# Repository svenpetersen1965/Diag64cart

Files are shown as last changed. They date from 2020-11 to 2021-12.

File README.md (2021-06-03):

# Diag64cart
The Diag64cart is a C64/C128 cartridge PCB, that is especially made for the need of diagnostic software, like Dead Test Rev. 781220 and Diagnostic Rev. 586220. The Diag64cart is derived from the Versa64cart (https://github.com/bwack/Versa64Cart), it lacks of the ability to be a 16k cartridge, though.
The geometry of this cart was especially made for the cheap Maszczyk KM-20 and the Kradex Z7 cartridge cases. Those are available from https://restore-store.de/ or https://www.tme.eu.
Dead Test and Diagnostic reside in two different address spaces of the C64. Also, they are differently configured via GAME  or EXROM and use different chip select signals (ROMH or ROML). 

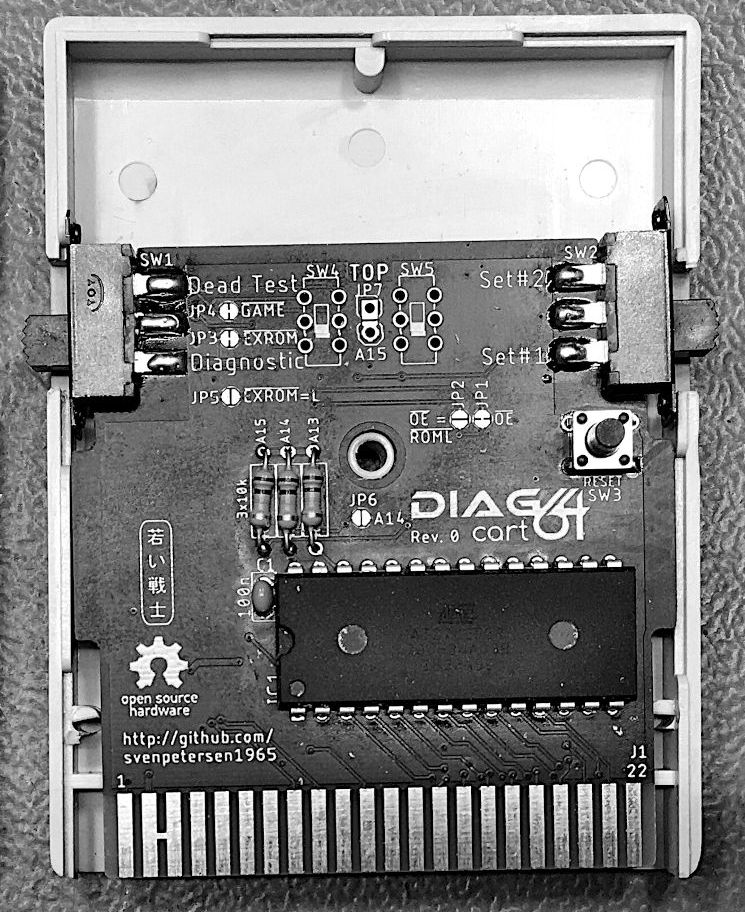
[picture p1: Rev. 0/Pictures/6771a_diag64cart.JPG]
Diag64cart


This repository contains binary files from other projects. The sources can be found in documen 164-6-01-** or here:
1.	(Commodore) Diagnostic Rev. 586220 (C64) (Version +0.5):  http://blog.worldofjani.com/?p=164
2.	(Commodore) Dead Test Rev. 781220 (C64):  http://blog.worldofjani.com/?p=164
3.	STID Dead Test (v1.2.0): https://github.com/stid/kick-c64-dead-test
4.	(Commodore) Diagnostic Rev. 785260 (C128):  http://blog.worldofjani.com/?p=164
5.	(Commodore) Diagnostic Rev. 588121 (C128):  http://blog.worldofjani.com/?p=164
6.	1541 Diagnostic (World of Jani): : http://blog.worldofjani.com/?p=2180
7.	Diag 4.1.1.: http://blog.worldofjani.com/?p=164 

BOM value (12.12.2020): 9.79€

Check out the 3D printed cartridge case from <a href="https://www.thingiverse.com/thing:4759098">retrorewind.ca</a>.

# The burn-In Software
This software requires modification of the default Configuration, since all four cartridges require EXROM=0 and Chip Select=ROML.

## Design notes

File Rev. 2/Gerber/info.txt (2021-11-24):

      
       Board: Diag64Cart
       Rev.:  2
  
       Files:
       ======
  
       All Gerber files are generated in extended gerber format (RS274X)
       *.TOP        : Film top copper
       *.BOT        :  -"- bottom copper
       *.STC        :  -"- top soldermask 
       *.STS        :  -"- bottom soldermask
       *.PLC        :  -"- silk screen top
       *.DK         : Drills plated Through (Excellon)
       *.NDK        : Drills not plated Through (Excellon)
       *.OUT        : Board outline

       Board Size:
       ===========
       Length     :   66.0 mm
       Width      :   63.3 mm
       Thickness  :   1.6 mm
       Material   :   FR 4
       Copper     :   35 um
       Surface    :   HASL
       
       Remarks:
       ========
       minimum drill: 0.35mm
       minimum width: 8 mil
       minimum distance: 6 mil

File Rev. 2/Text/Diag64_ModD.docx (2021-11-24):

Commodore C64: Diag64cart Rev. 2

Module Description

# Introduction

The Diag64cart is a C64/C128 cartridge PCB, that is especially made for the need of diagnostic software, like Dead Test Rev. 781220 and Diagnostic Rev. 586220. The Diag64cart is derived from the Versa64cart (https://github.com/bwack/Versa64Cart), it lacks of the ability to be a 16k cartridge, though.

The geometry of this cart was especially made for the cheap Maszczyk (https://www.maszczyk.pl/en.html) KM-20 and the Kradex (https://www.kradex.de/) Z7 cartridge cases. Those are available from https://restore-store.de/ or https://www.tme.eu.

Dead Test and Diagnostic reside in two different address spaces of the C64. Also, they are differently configured via or and use different chip select signals ( or ).

# Select Switches

While Dead Test replaces the Kernal, Diagnostic is an 8k auto-start cartridge at address $8000. Diag64cart has a fix assignment of EPROM offset addresses (via A13) and the cartridge type, which is done by the left DTDP switch SW1.

The right switch (SW2) only switches the EPROM offset address A14. This results in four possible software banks in the EPROM. The use of 27C256 or 27C512 is recommended.

The switches are a cheap, simple and comfortable way to reconfigure the cartridge for the different diagnostic tools. The configuration of the cartridge can be modified with solder bridges.

SW1 | SW2 | | | Chip Select | A13 | A14 | Type | EPROM
down | down | HIGH | LOW | | LOW | LOW | Diagnostic | $0000
up | down | LOW | HIGH | | HIGH | LOW | Dead Test | $2000
down | up | HIGH | LOW | | LOW | HIGH | Diagnostic | $4000
up | up | LOW | HIGH | | HIGH | HIGH | Dead Test | $6000

Table 1: Default Configuration: assignment of switches and software type

The connection between SW1, , , chip select and A13 implies an order of the type of software/cartridge in the EPROM memory.

Do not confuse the EPROM offset address with the memory address of the cartridge in the C64/C128. A selected cartridge will appear in the computer’s address, that is specified by the chip select (that is $8000 for and $C000 for ). The EPROM offset address is the address in the programming buffer/EPROM, where the binaries reside.

# Configuration with solder bridges

The default configuration is described in the previous chapter. This can be modified with solder bridges.

E.G. the C128 works differently than the C64. If the C128 finds either or LOW, it will boot into the C64 mode. For a C128 cartridge, both signals have to be high.

Solder bridge | Default | When closed | Note
JP1 | closed | Chip select () switched by SW1 | If JP2 is closed, open JP1
JP2 | open | Chip select always | e.g. for only diagnostic software or C128 mode only
JP3 | closed | switched by SW1, A13 = | Open for permanent settings for
JP4 | closed | switched by SW1 | Open for permanent settings for
JP5 | open | always LOW | e.g. for C64 diagnostic only
JP6 | open | A14 always LOW | In case only two software required and A14 not installed
JP7 | open | A15 always LOW | Close for EPROM type 27C512
JP8 | open | always LOW | e.g. for C64 dead test only

Table 2: Configuration of the solder bridges

# Example configurations

## EPROM Type 27C512

If a 27C512 is used, it might be desired to program the EPROM starting at offset address $0000. For this purpose, A15 has to be LOW. This requires JP7 to be closed.

## EPROM Type 27C256

This is the default EPROM type. No modifications are required. JP7 is open be default, that means A15 is HIGH (that is the VPP input on a 27C256).

## EPROM Type 27C128

This 16k EPROM can hold two 8k software. In this case, SW2 (which switches A14 between LOW and HIGH =open, due to the pull-up resistor). In a 27C128, this pin is /PGM, which should be HIGH. The switch SW2 can just be omitted, no further modification required, since the pull-up resistor R3 does the job.

## EPROM Type 27C64

This is actually an abuse, since a 27C64 can only hold 8k of software. So, no switch is required at all. A13 (Pin 26) is a “not connected” pin of the EPROM. The pull-up R4 can stay. It does not harm the function of the EPROM, but it is not required. In case the cartridge software resides in $8000, close JP2 and JP5. An 8k cartridge at $C000 can be achieved by bridging the solder pads of SW1 to mimic it in up position. The solder pads of the alternative switch SW4 might come in handy in this case.

## C64 and C128 Diagnostic Cartridge

The C128 requires both, and to be HIGH (=open) and the chip select () to be . For this purpose, open JP4 and JP1 and close JP2. While the 8k memory at $0000 and $4000 are reserved for C64 software and the 8k memory banks at $2000 and $6000 are reserved for C128 cartridge software.

## C128 Cartridge Only

Again, both , and , have to be HIGH (=open) and the chip select () has to be . For this purpose, open JP1, JP3, JP4 and close JP2.

## C64 Diagnostic Cartridge Only

In case it is desired to have all software reside at $8000, needs to be open, needs to be low and the chip select has to be . For this purpose, open JP1, JP3 and JP4 and close JP2 and JP5.

# Switches

The switches SW1 and SW2 are built in sideways. They are DPDT slide switches with a pin pitch of 4mm. The hole distance is 19mm (which is not important for this project, but just a part of the switches specification). The height of the switch body is 6.9mm. This is met be the reichelt.de part number T217 or the AliExpress SS22F25-G7, but obviously, there are more 199mm pitch panel mount switches, that meet these specifications.

Alternatively, there are footprints (SW4 and SW5) for the also wide spread AliExpress mini slide switches MSS22D18.

# EPROMs

Four different types/sizes of EPROMs can be used with the Versa64Cart, not all settings make sense with them. Their pin out is shown in Table 3.

The effect of the settings and the recommended configurations are shown in Table 4.

27C64
| 27C128
| | 27C256
| | | 27C512
| | | | SOCKET
Vpp | Vpp | Vpp | A15 | 1 | A15 | VCC | 28 | VCC | VCC | VCC | VCC
A12 | A12 | A12 | A12 | 2 | A12 | A14 | 27 | A14 | A14 | /PGM | /PGM
A7 | A7 | A7 | A7 | 3 | A7 | A13 | 26 | A13 | A13 | A13 | n.c.
A6 | A6 | A6 | A6 | 4 | A6 | A8 | 25 | A8 | A8 | A8 | A8
A5 | A5 | A5 | A5 | 5 | A5 | A9 | 24 | A9 | A9 | A9 | A9
A4 | A4 | A4 | A4 | 6 | A4 | A11 | 23 | A11 | A11 | A11 | A11
A3 | A3 | A3 | A3 | 7 | A3 | /OE | 22 | /G/Vpp | /G | /G | /G
A2 | A2 | A2 | A2 | 8 | A2 | A10 | 21 | A10 | A10 | A10 | A10
A1 | A1 | A1 | A1 | 9 | A1 | GND | 20 | /E | /E | /E | /E
A0 | A0 | A0 | A0 | 10 | A0 | D7 | 19 | D7 | D7 | D7 | D7
D0 | D0 | D0 | D0 | 11 | D0 | D6 | 18 | D6 | D6 | D6 | D6
D1 | D1 | D1 | D1 | 12 | D1 | D5 | 17 | D5 | D5 | D5 | D5
D2 | D2 | D2 | D2 | 13 | D2 | D4 | 16 | D4 | D4 | D4 | D4
GND | GND | GND | GND | 14 | GND | D3 | 15 | D3 | D3 | D3 | D3

Table 3: EPROM pin compatibility

EPROM | Size | A15 | A14 | A13 | 16k
27C512 | 64kx8 | yes | yes | yes | yes
27C256 | 32kx8 | HIGH | yes | yes | yes
27C128 | 16kx8 | HIGH | HIGH | yes | yes
27C64 | 8kx8 | HIGH | HIGH | HIGH | no

Table 4: Settings per EPROM type

In case Vpp is located at a dedicated pin (pin 1), A15 has no effect anymore. A HIGH level is recommended (switch is off) . The /PGM Pin should be set HIGH. The n.c. (not connected) pin should be HIGH (with pull-up) or open. For an 8k EPROM, the 16k setting makes no sense.

# Using parallel EEPROMs

There are parallel EPROMs, which fit into the EPROM sockets. They do not require erasing with a UV eraser, like EPROMs, but the price is higher.

Since they can be written, which is controlled by the signal, but the Super Expander II cartridge is lacking of this functionality, this signal has to be HIGH (inactive). The 28C256 has the A14 signal connected to Pin 1, which is A15 of the EEPROM socket. This is no problem, but it has to be kept in mind, that the jumper for A15 has effect on the bank select A14 of the EPROM.

28C64
| 28C256
| | SOCKET
n.c. | A14 | 1 | A15 | VCC | 28 | VCC | VCC
A12 | A12 | 2 | A12 | A14 | 27 | /WE | /WE
A7 | A7 | 3 | A7 | A13 | 26 | A13 | n.c
A6 | A6 | 4 | A6 | A8 | 25 | A8 | A8
A5 | A5 | 5 | A5 | A9 | 24 | A9 | A9
A4 | A4 | 6 | A4 | A11 | 23 | A11 | A11
A3 | A3 | 7 | A3 | /OE | 22 | /G/Vpp | /OE
A2 | A2 | 8 | A2 | A10 | 21 | A10 | A10
A1 | A1 | 9 | A1 | GND | 20 | /E | /CE
A0 | A0 | 10 | A0 | D7 | 19 | D7 | D7
D0 | D0 | 11 | D0 | D6 | 18 | D6 | D6
D1 | D1 | 12 | D1 | D5 | 17 | D5 | D5
D2 | D2 | 13 | D2 | D4 | 16 | D4 | D4
GND | GND | 14 | GND | D3 | 15 | D3 | D3

Table 5: EEPROM pin compatibility

EEPROM | Size | A15 | A14 | A13
28C256 | 32kx8 | =A14 | OPEN | yes
28C64 | 8kx8 | OPEN | OPEN | OPEN

Table 6: Settings per EEPROM type

# Dimensions

The dimensions are made to fit the said cartridge cases.

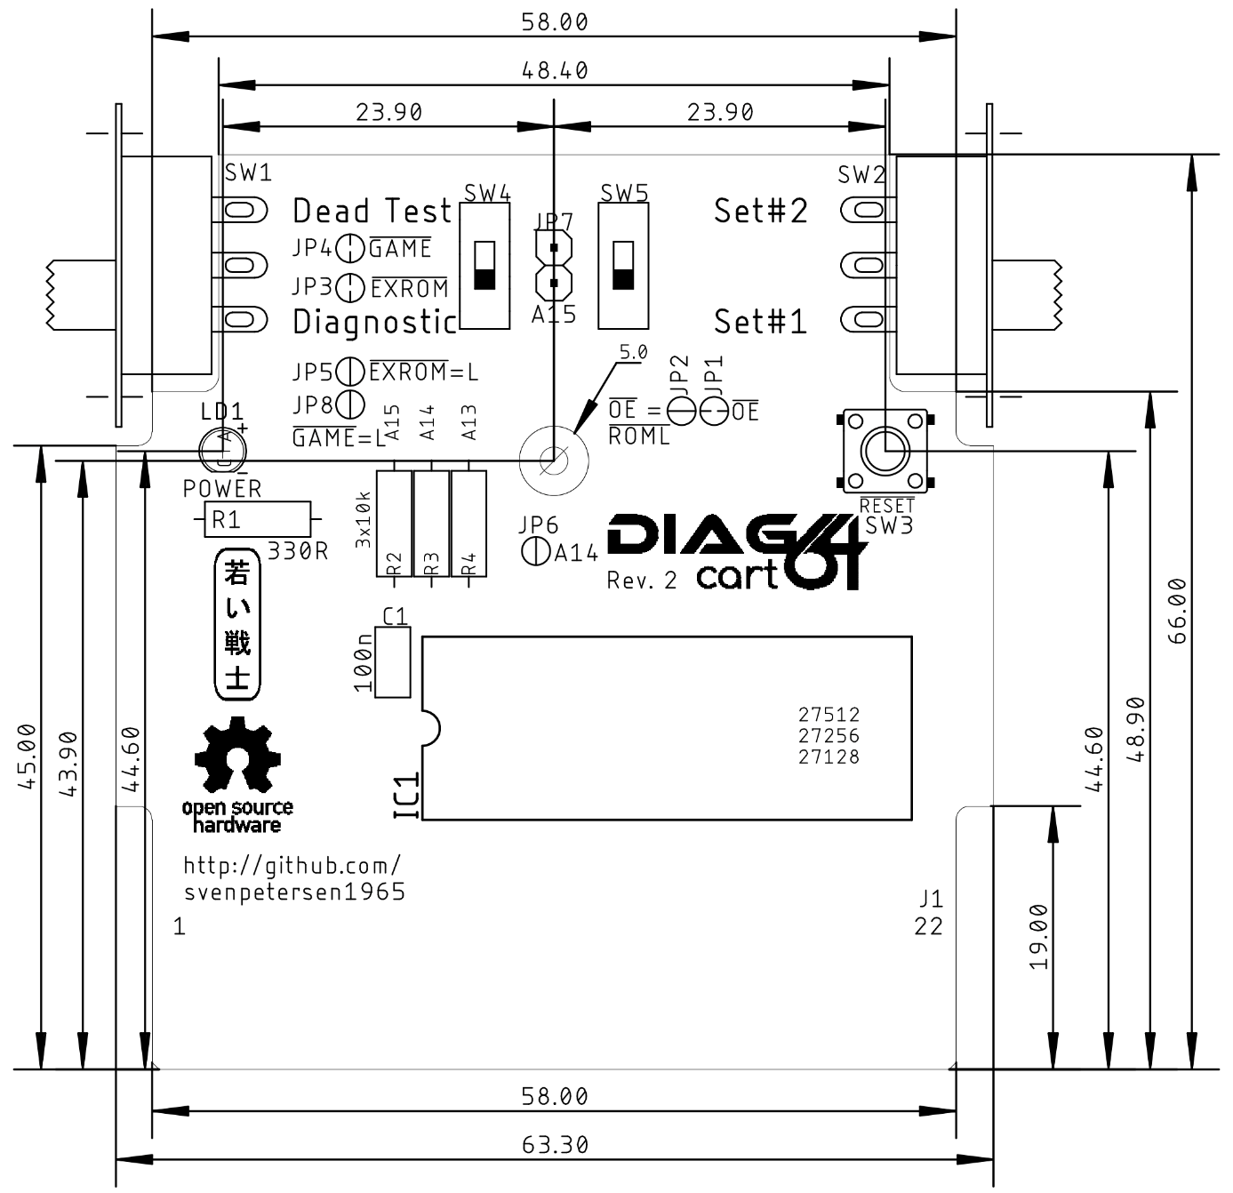
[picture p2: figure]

Figure 1: Dimensions

The Maszczyk KM-20 and the Kradex Z7 cartridge cases both fit the Diag64cart. The dimensions are slightly different, though.

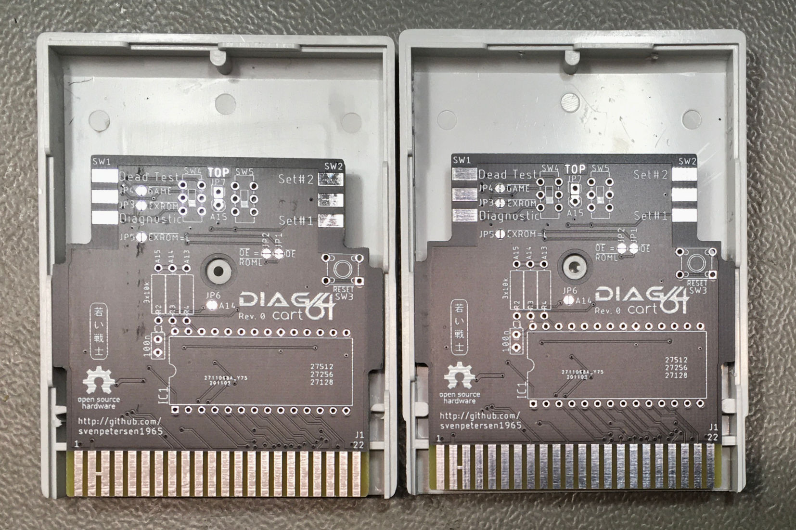
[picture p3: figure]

Figure 2: Maszczyk KM-20(left), Kradex Z7 (right)

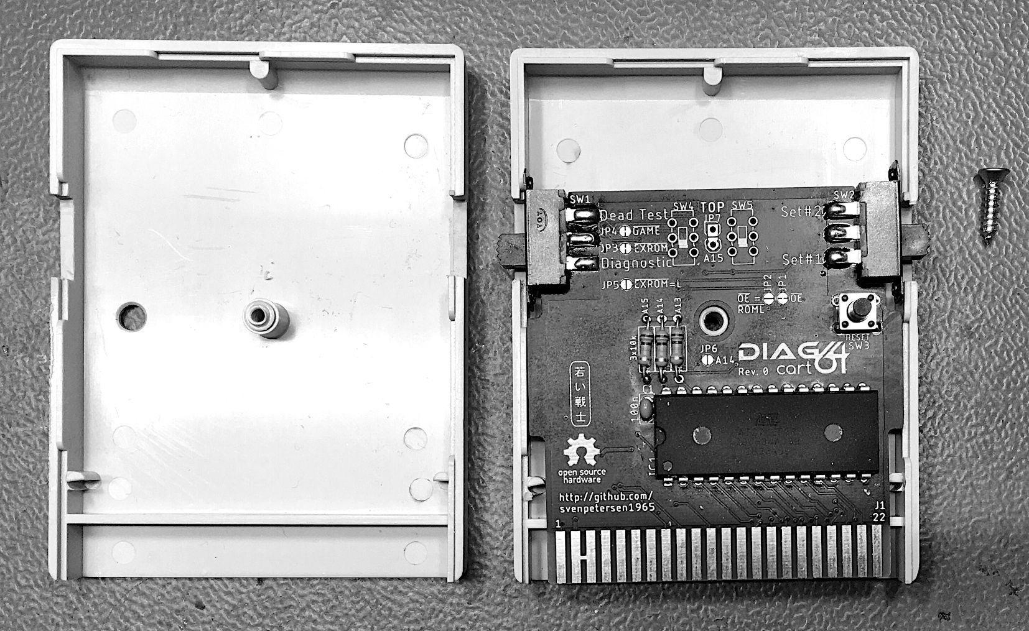
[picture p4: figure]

Figure 3: Diag64cart in the finished KM-20 case

# Suggested Software

This cartridge is made for C64 (and C128) Diagnostic software. So, the selection of suggested software is for this kind of purpose.

1. (Commodore) Diagnostic Rev. 586220 (C64) (Version +0.5)
2. (Commodore) Dead Test Rev. 781220 (C64)
3. STID Dead Test (v1.2.0)
4. (Commodore) Diagnostic Rev. 785260 (C128)
5. (Commodore) Diagnostic Rev. 588121 (C128)
6. 1541 Diagnostic (World of Jani)
7. Diag 4.1.1.

Diagnostic Rev. 586220 and Diag. 4.1.1 work with the same diagnostic harness (https://github.com/svenpetersen1965/C64-Diagnostic-Rev.-586220-Harness). While Diagnostic Rev. 586220 is still the diagnostic tool of my choice, Diag 4.1.1 is a bit different and might be useful as a second instance.

Dead Test Rev. 781220 is THE dead test program, that can reveal RAM problems without requiring a working display. The first-choice software to debug a black screen.

STID Dead Test is a modification of the Commodore Dead Test Rev. 781220 it has some nice new features (e.g. tests the SID filters). It can be obtained here: https://github.com/stid/kick-c64-dead-test. The binary files can be found in the releases of this project. No compiling and building required.

The 1541 Diagnostics is a very nice toolkit for testing and debugging a Commodore 1541 (or Oceanic OC-118) disk drive. It can be obtained here: http://blog.worldofjani.com/?p=2180

I have downloaded all other binaries from World of Jani: http://blog.worldofjani.com/?p=164

# Revision History

## Rev. 0

- Fully functional prototype

## Rev. 1

- JP8 new
- Lower corner of the “shoulders” was moved down by 6mm (19mm instead of 25mm) to reduce the movement of the PCB.

## Rev. 2

- Power LED added

Diag64_ModD.docx 24.11.2021 22:10 Drafted by Sven Petersen Page 2 of 2 Doc.-No.: 164-6-01-02

Diag64_ModD.docx 24.11.2021 22:10 Drafted by Sven Petersen Page 1 of 1 Doc.-No.: 000-6-00-00

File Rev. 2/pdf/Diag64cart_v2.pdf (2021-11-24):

# Project Documentation

## Commodore C64: Diag64cart

## Project number: 164

## Revision: 2

## Date: 24.11.2021

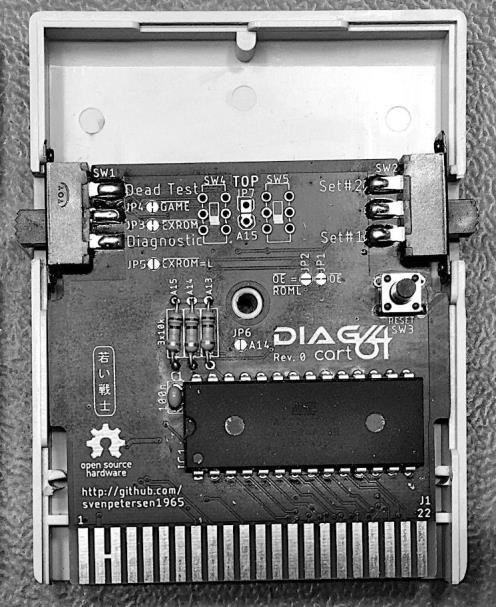
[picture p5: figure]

Diag64_ModD.docx | | 24.11.2021 22:10
Drafted by Sven Petersen | Page 1 of 8 | Doc.-No.: 164-6-01-02

### Commodore C64: Diag64cart Rev. 2

### Module Description

Table of Contents

## Introduction

The Diag64cart is a C64/C128 cartridge PCB, that is especially made for the need of diagnostic software, like Dead Test Rev. 781220 and Diagnostic Rev. 586220. The Diag64cart is derived from the Versa64cart (https://github.com/bwack/Versa64Cart), it lacks of the ability to be a 16k cartridge, though.

The geometry of this cart was especially made for the cheap Maszczyk (https://www.maszczyk.pl/en.html) KM-20 and the Kradex (https://www.kradex.de/) Z7 cartridge cases. Those are available from https://restore-store.de/ or https://www.tme.eu.

Dead Test and Diagnostic reside in two different address spaces of the C64. Also, they are differently configured via GAME or EXROM and use different chip select signals ( ROMH or ROML ).

Drafted by Sven Petersen | Page 2 of 8 | Doc.-No.: 164-6-01-02

## Select Switches

While Dead Test replaces the Kernal, Diagnostic is an 8k auto-start cartridge at address $8000. Diag64cart has a fix assignment of EPROM offset addresses (via A13) and the cartridge type, which is done by the left DTDP switch SW1.

The right switch (SW2) only switches the EPROM offset address A14. This results in four possible software banks in the EPROM. The use of 27C256 or 27C512 is recommended.

The switches are a cheap, simple and comfortable way to reconfigure the cartridge for the different diagnostic tools. The configuration of the cartridge can be modified with solder bridges.

SW1 | SW2 | GAME | EXROM
Chip Select | A13 | A14 | Type | EPROM
down | down | HIGH | LOW | ROML | LOW | LOW | Diagnostic | $0000
up | down | LOW | HIGH | ROMH | HIGH | LOW | Dead Test | $2000
down | up | HIGH | LOW | ROML | LOW | HIGH | Diagnostic | $4000
up | up | LOW | HIGH | ROMH | HIGH | HIGH | Dead Test | $6000

Table 1: Default Configuration: assignment of switches and software type

The connection between SW1, GAME , EXROM , chip select and A13 implies an order of the type of software/cartridge in the EPROM memory.

Do not confuse the EPROM offset address with the memory address of the cartridge in the C64/C128. A selected cartridge will appear in the computer’s address, that is specified by the chip

select (that is $8000 for ROML and $C000 for ROMH ). The EPROM offset address is the address in the programming buffer/EPROM, where the binaries reside.

## Configuration with solder bridges

The default configuration is described in the previous chapter. This can be modified with solder bridges.

E.G. the C128 works differently than the C64. If the C128 finds either GAME or EXROM LOW, it will boot into the C64 mode. For a C128 cartridge, both signals have to be high.

Solder bridge Default When closed | Note
JP1 | closed | Chip select ( OE ) switched by SW1 | If JP2 is closed, open JP1
JP2 | open | Chip select always ROML | e.g. for only diagnostic software or C128 mode only
JP3 | closed | EXROM switched by SW1, A13 = EXROM | Open for permanent settings for EXROM
JP4 | closed | GAME switched by SW1 | Open for permanent settings for GAME
JP5 | open | EXROM always LOW | e.g. for C64 diagnostic only
JP6 | open | A14 always LOW | In case only two software required and A14 not installed

Drafted by Sven Petersen | Page 3 of 8 | Doc.-No.: 164-6-01-02
Solder bridge Default When closed | Note
JP7 | open | A15 always LOW | Close for EPROM type 27C512
JP8 | open | GAME always LOW | e.g. for C64 dead test only

Table 2: Configuration of the solder bridges

## Example configurations

### EPROM Type 27C512

If a 27C512 is used, it might be desired to program the EPROM starting at offset address $0000. For this purpose, A15 has to be LOW. This requires JP7 to be closed.

### EPROM Type 27C256

This is the default EPROM type. No modifications are required. JP7 is open be default, that means A15 is HIGH (that is the VPP input on a 27C256).

### EPROM Type 27C128

This 16k EPROM can hold two 8k software. In this case, SW2 (which switches A14 between LOW and HIGH =open, due to the pull-up resistor). In a 27C128, this pin is /PGM, which should be HIGH. The switch SW2 can just be omitted, no further modification required, since the pull-up resistor R3 does the job.

### EPROM Type 27C64

This is actually an abuse, since a 27C64 can only hold 8k of software. So, no switch is required at all. A13 (Pin 26) is a “not connected” pin of the EPROM. The pull-up R4 can stay. It does not harm the function of the EPROM, but it is not required. In case the cartridge software resides in $8000, close JP2 and JP5. An 8k cartridge at $C000 can be achieved by bridging the solder pads of SW1 to mimic it in up position. The solder pads of the alternative switch SW4 might come in handy in this case.

### C64 and C128 Diagnostic Cartridge

The C128 requires both, GAME and EXROM to be HIGH (=open) and the chip select ( OE ) to

be ROML . For this purpose, open JP4 and JP1 and close JP2. While the 8k memory at $0000 and $4000 are reserved for C64 software and the 8k memory banks at $2000 and $6000 are reserved for C128 cartridge software.

### C128 Cartridge Only

Again, both , GAME and EXROM , have to be HIGH (=open) and the chip select ( OE ) has to

be ROML . For this purpose, open JP1, JP3, JP4 and close JP2.

### C64 Diagnostic Cartridge Only

In case it is desired to have all software reside at $8000, GAME needs to be open, EXROM needs

to be low and the chip select has to be ROML . For this purpose, open JP1, JP3 and JP4 and close JP2 and JP5.

Drafted by Sven Petersen | Page 4 of 8 | Doc.-No.: 164-6-01-02

## Switches

The switches SW1 and SW2 are built in sideways. They are DPDT slide switches with a pin pitch of 4mm. The hole distance is 19mm (which is not important for this project, but just a part of the switches specification). The height of the switch body is 6.9mm. This is met be the reichelt.de part number T217 or the AliExpress SS22F25-G7, but obviously, there are more 199mm pitch panel mount switches, that meet these specifications.

Alternatively, there are footprints (SW4 and SW5) for the also wide spread AliExpress mini slide switches MSS22D18.

## EPROMs

Four different types/sizes of EPROMs can be used with the Versa64Cart, not all settings make sense with them. Their pin out is shown in Table 3.

The effect of the settings and the recommended configurations are shown in Table 4.

27C64

| 27C128
| 27C256
| 27C512
| SOCKET
Vpp | Vpp | Vpp | A15 | 1 | A15 | VCC | 28 | VCC | VCC | VCC | VCC
A12 | A12 | A12 | A12 | 2 | A12 | A14 | 27 | A14 | A14 | /PGM | /PGM
A7 | A7 | A7 | A7 | 3 | A7 | A13 | 26 | A13 | A13 | A13 | n.c.
A6 | A6 | A6 | A6 | 4 | A6 | A8 | 25 | A8 | A8 | A8 | A8
A5 | A5 | A5 | A5 | 5 | A5 | A9 | 24 | A9 | A9 | A9 | A9
A4 | A4 | A4 | A4 | 6 | A4 | A11 | 23 | A11 | A11 | A11 | A11
A3 | A3 | A3 | A3 | 7 | A3 | /OE | 22 | /G/Vpp | /G | /G | /G
A2 | A2 | A2 | A2 | 8 | A2 | A10 | 21 | A10 | A10 | A10 | A10
A1 | A1 | A1 | A1 | 9 | A1 | GND | 20 | /E | /E | /E | /E
A0 | A0 | A0 | A0 | 10 | A0 | D7 | 19 | D7 | D7 | D7 | D7
D0 | D0 | D0 | D0 | 11 | D0 | D6 | 18 | D6 | D6 | D6 | D6
D1 | D1 | D1 | D1 | 12 | D1 | D5 | 17 | D5 | D5 | D5 | D5
D2 | D2 | D2 | D2 | 13 | D2 | D4 | 16 | D4 | D4 | D4 | D4
GND | GND | GND | GND | 14 | GND | D3 | 15 | D3 | D3 | D3 | D3

Table 3: EPROM pin compatibility

Drafted by Sven Petersen | Page 5 of 8 | Doc.-No.: 164-6-01-02
EPROM | Size | A15 | A14 | A13 | 16k
27C512 | 64kx8 | yes | yes | yes | yes
27C256 | 32kx8 | HIGH | yes | yes | yes
27C128 | 16kx8 | HIGH | HIGH | yes | yes
27C64 | 8kx8 | HIGH | HIGH | HIGH | no
Table 4: Settings per EPROM type

In case Vpp is located at a dedicated pin (pin 1), A15 has no effect anymore. A HIGH level is recommended (switch is off) . The /PGM Pin should be set HIGH. The n.c. (not connected) pin should be HIGH (with pull-up) or open. For an 8k EPROM, the 16k setting makes no sense.

## Using parallel EEPROMs

There are parallel EPROMs, which fit into the EPROM sockets. They do not require erasing with a UV eraser, like EPROMs, but the price is higher.

Since they can be written, which is controlled by the WE signal, but the Super Expander II cartridge is lacking of this functionality, this signal has to be HIGH (inactive). The 28C256 has the A14 signal connected to Pin 1, which is A15 of the EEPROM socket. This is no problem, but it has to be kept in mind, that the jumper for A15 has effect on the bank select A14 of the EPROM.

28C64

| 28C256
| SOCKET
n.c. | A14 | 1 | A15 | VCC | 28 | VCC | VCC
A12 | A12 | 2 | A12 | A14 | 27 | /WE | /WE
A7 | A7 | 3 | A7 | A13 | 26 | A13 | n.c
A6 | A6 | 4 | A6 | A8 | 25 | A8 | A8
A5 | A5 | 5 | A5 | A9 | 24 | A9 | A9
A4 | A4 | 6 | A4 | A11 | 23 | A11 | A11
A3 | A3 | 7 | A3 | /OE | 22 | /G/Vpp | /OE
A2 | A2 | 8 | A2 | A10 | 21 | A10 | A10
A1 | A1 | 9 | A1 | GND | 20 | /E | /CE
A0 | A0 | 10 | A0 | D7 | 19 | D7 | D7
D0 | D0 | 11 | D0 | D6 | 18 | D6 | D6
D1 | D1 | 12 | D1 | D5 | 17 | D5 | D5
D2 | D2 | 13 | D2 | D4 | 16 | D4 | D4
GND | GND | 14 | GND | D3 | 15 | D3 | D3

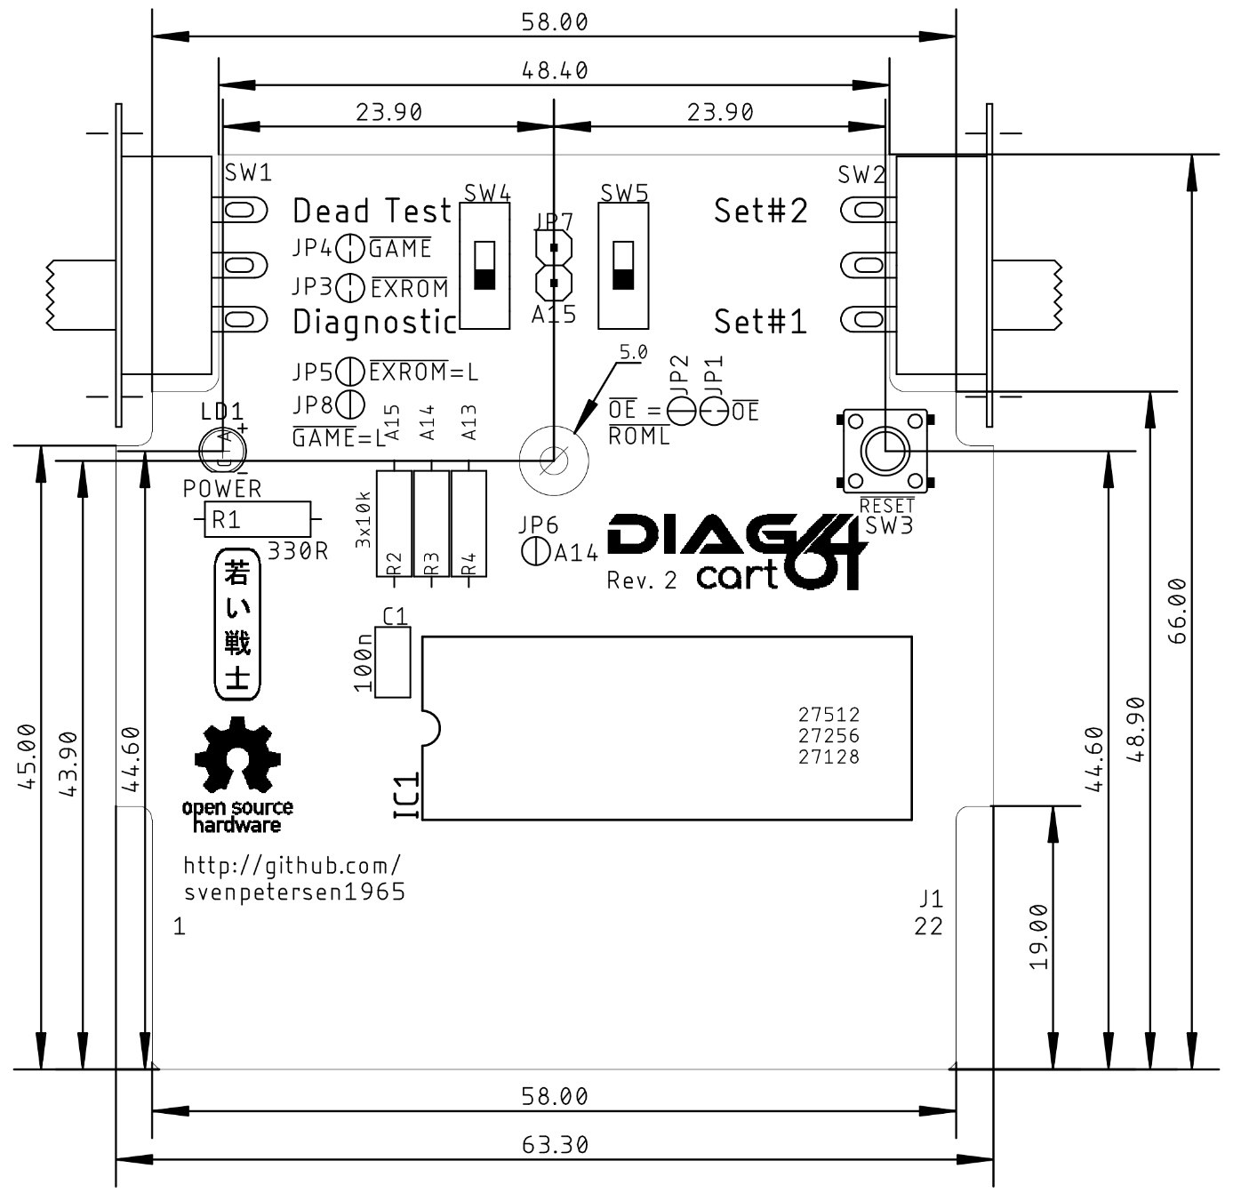
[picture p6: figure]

Drafted by Sven Petersen | Page 6 of 8 | Doc.-No.: 164-6-01-02

Table 5: EEPROM pin compatibility

EEPROM | Size | A15 | A14 | A13
28C256 | 32kx8 | =A14 | OPEN | yes
28C64 | 8kx8 | OPEN | OPEN | OPEN
Table 6: Settings per EEPROM type

## Dimensions

The dimensions are made to fit the said cartridge cases.

Figure 1: Dimensions

The Maszczyk KM-20 and the Kradex Z7 cartridge cases both fit the Diag64cart. The dimensions are slightly different, though.

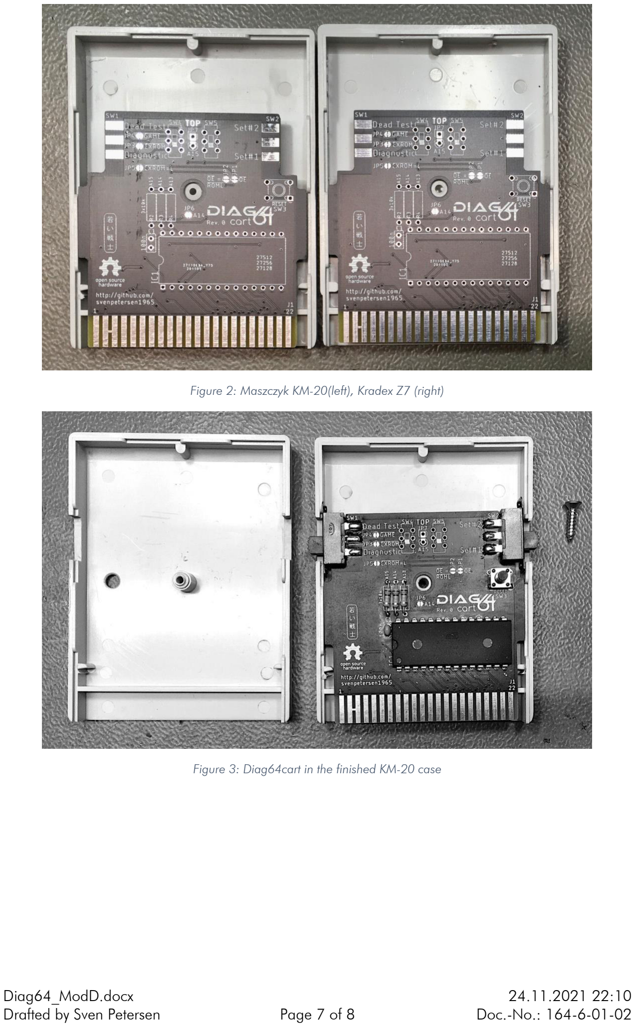
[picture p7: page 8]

Drafted by Sven Petersen | Page 7 of 8 | Doc.-No.: 164-6-01-02

Figure 2: Maszczyk KM-20(left), Kradex Z7 (right)

Figure 3: Diag64cart in the finished KM-20 case

Drafted by Sven Petersen | Page 8 of 8 | Doc.-No.: 164-6-01-02

## Suggested Software

This cartridge is made for C64 (and C128) Diagnostic software. So, the selection of suggested software is for this kind of purpose.

1. (Commodore) Diagnostic Rev. 586220 (C64) (Version +0.5)
2. (Commodore) Dead Test Rev. 781220 (C64)

### 3. STID Dead Test (v1.2.0)

4. (Commodore) Diagnostic Rev. 785260 (C128)
5. (Commodore) Diagnostic Rev. 588121 (C128)
6. 1541 Diagnostic (World of Jani)
7. Diag 4.1.1.

Diagnostic Rev. 586220 and Diag. 4.1.1 work with the same diagnostic harness (https://github.com/svenpetersen1965/C64-Diagnostic-Rev.-586220-Harness). While Diagnostic Rev. 586220 is still the diagnostic tool of my choice, Diag 4.1.1 is a bit different and might be useful as a second instance.

Dead Test Rev. 781220 is THE dead test program, that can reveal RAM problems without requiring a working display. The first-choice software to debug a black screen.

STID Dead Test is a modification of the Commodore Dead Test Rev. 781220 it has some nice new features (e.g. tests the SID filters). It can be obtained here: https://github.com/stid/kick-c64-dead-test. (https://github.com/stid/kick-c64-dead-test) The binary files can be found in the releases of this project. No compiling and building required.

The 1541 Diagnostics is a very nice toolkit for testing and debugging a Commodore 1541 (or Oceanic OC-118) disk drive. It can be obtained here: http://blog.worldofjani.com/?p=2180

I have downloaded all other binaries from World of Jani: http://blog.worldofjani.com/?p=164

## Revision History

### Rev. 0

- Fully functional prototype

### Rev. 1

- JP8 new

### - Lower corner of the “shoulders” was moved down by 6mm (19mm instead of 25mm) to

reduce the movement of the PCB.

### Rev. 2

- Power LED added

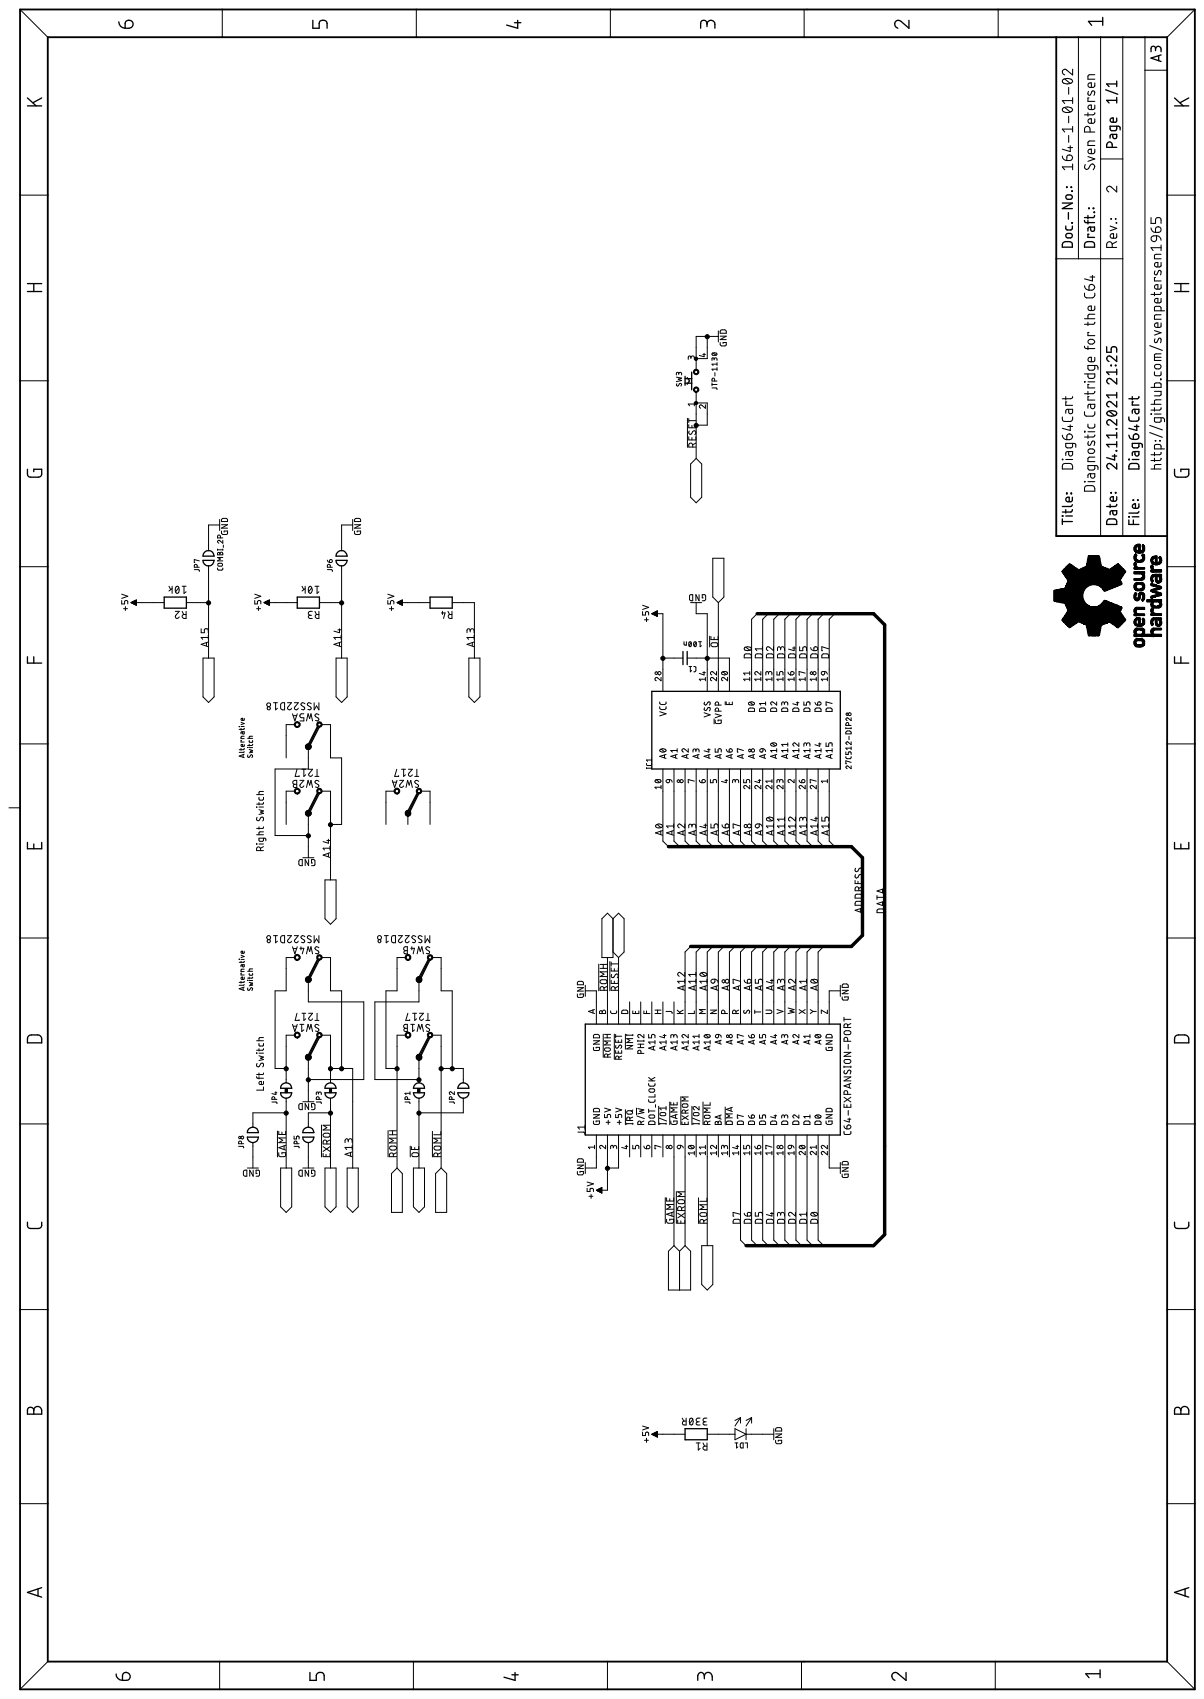
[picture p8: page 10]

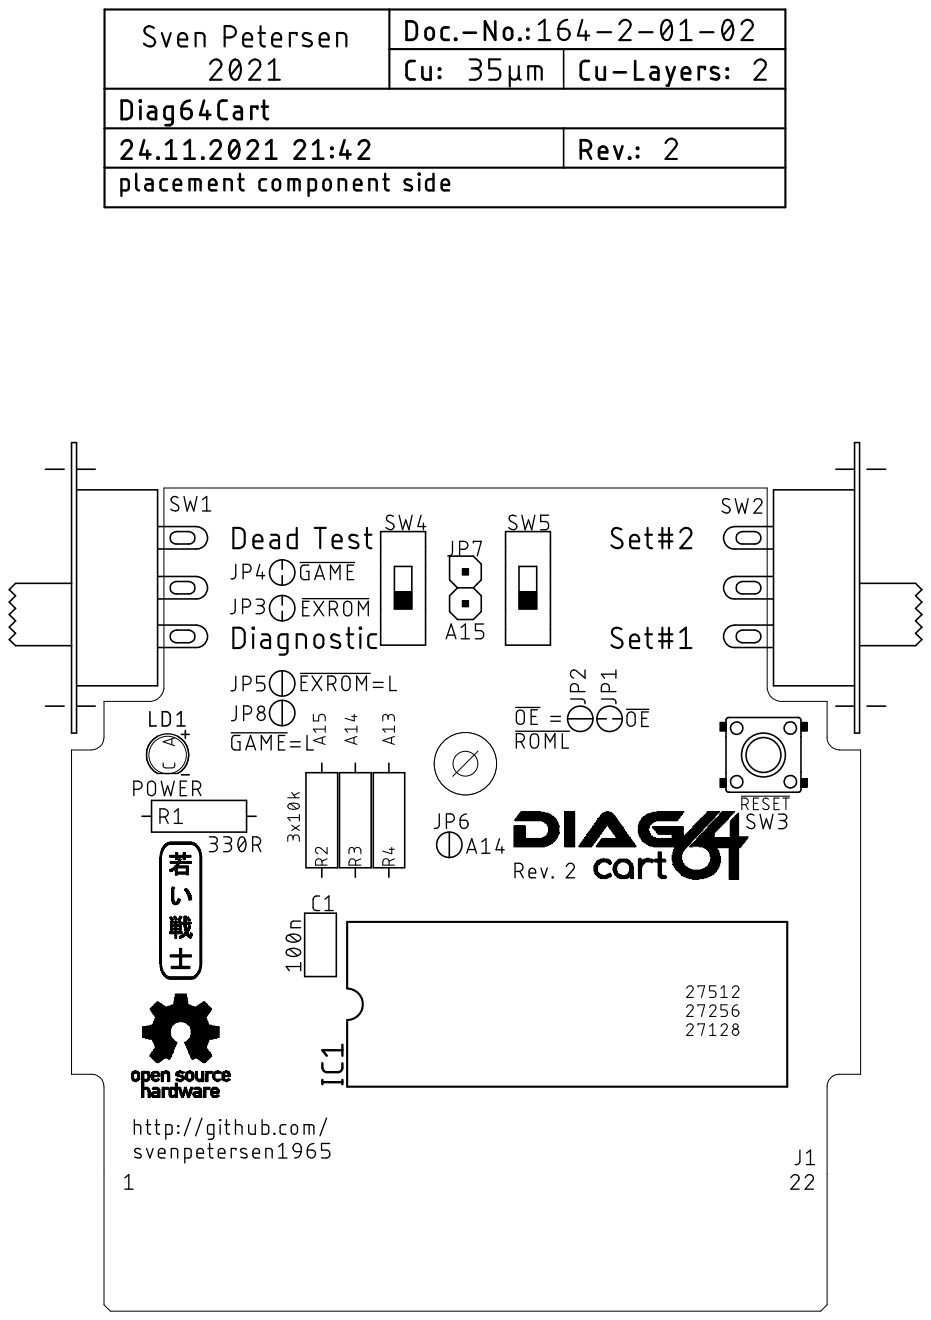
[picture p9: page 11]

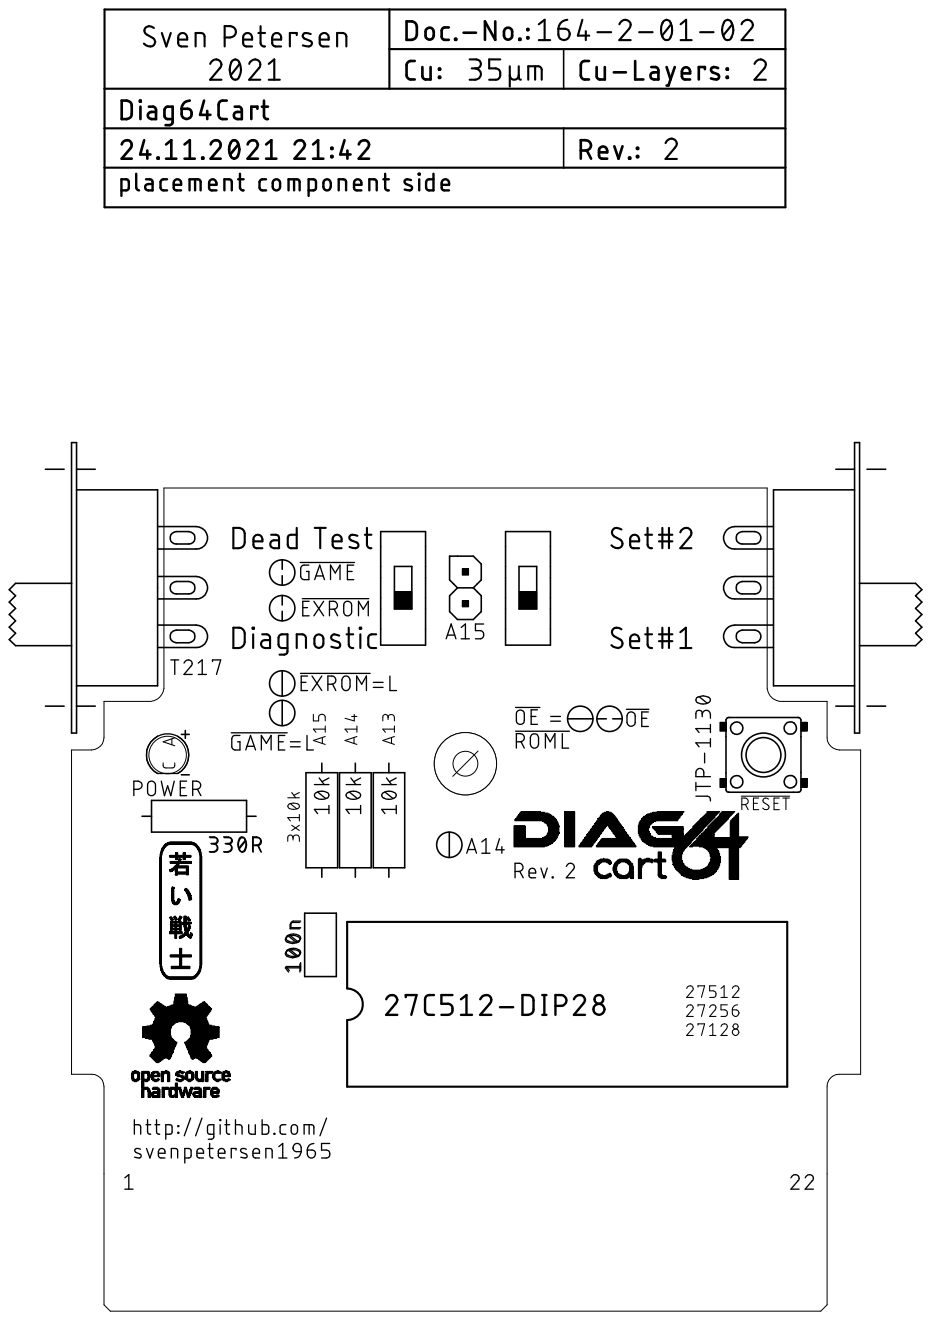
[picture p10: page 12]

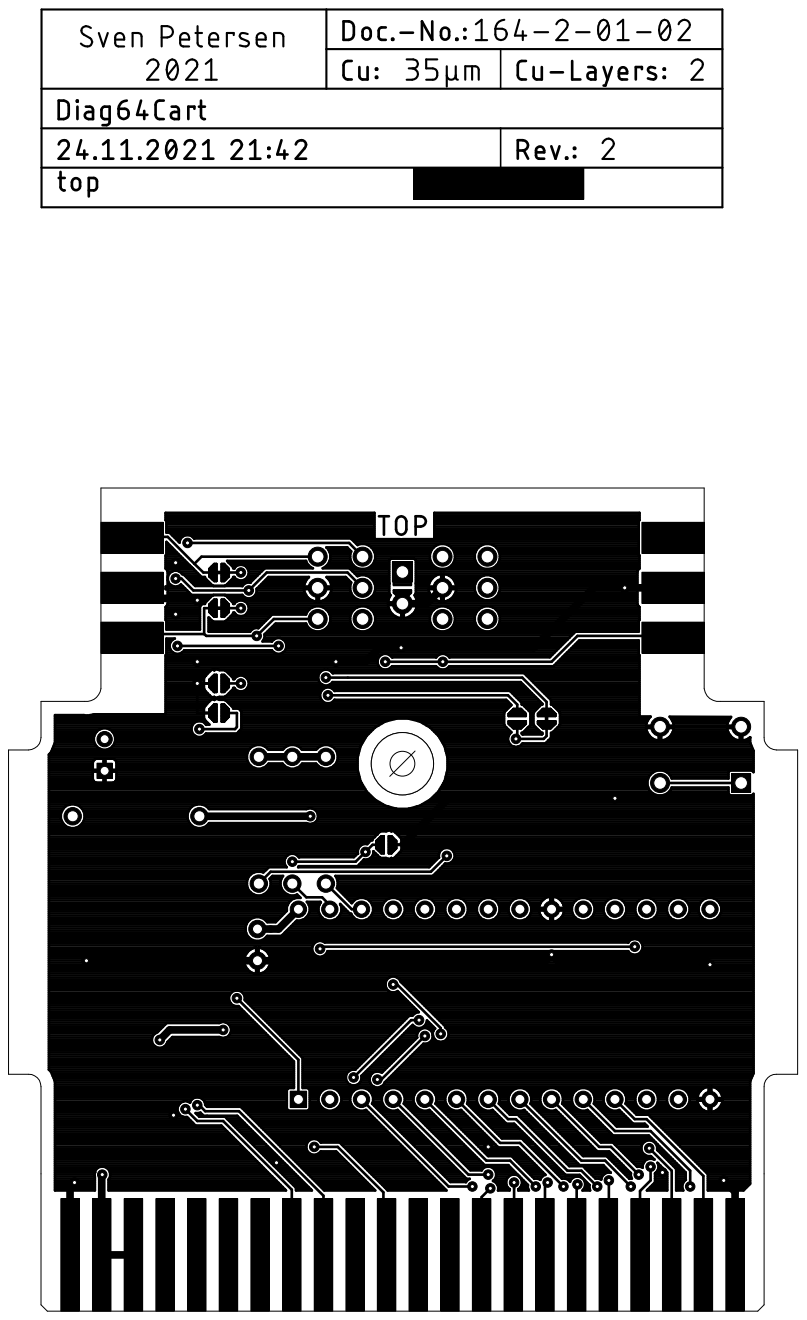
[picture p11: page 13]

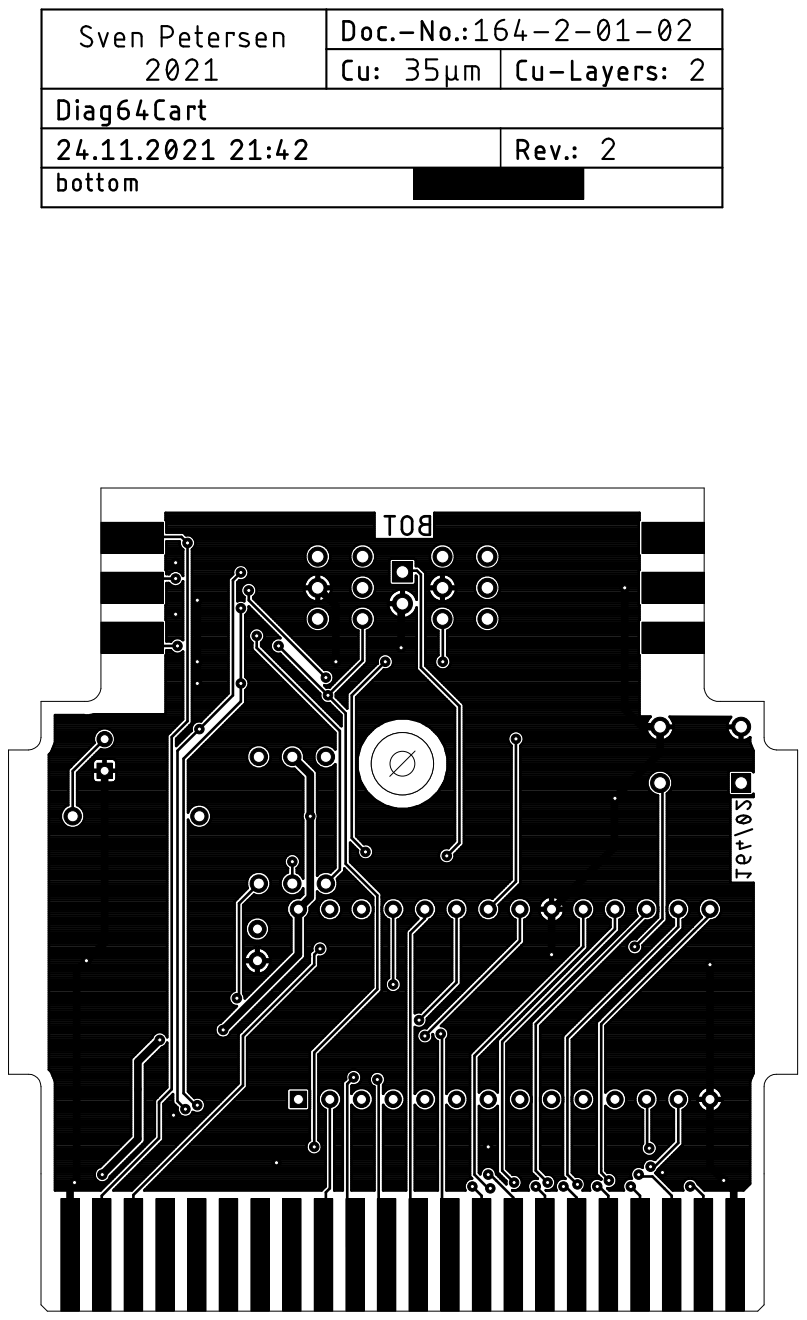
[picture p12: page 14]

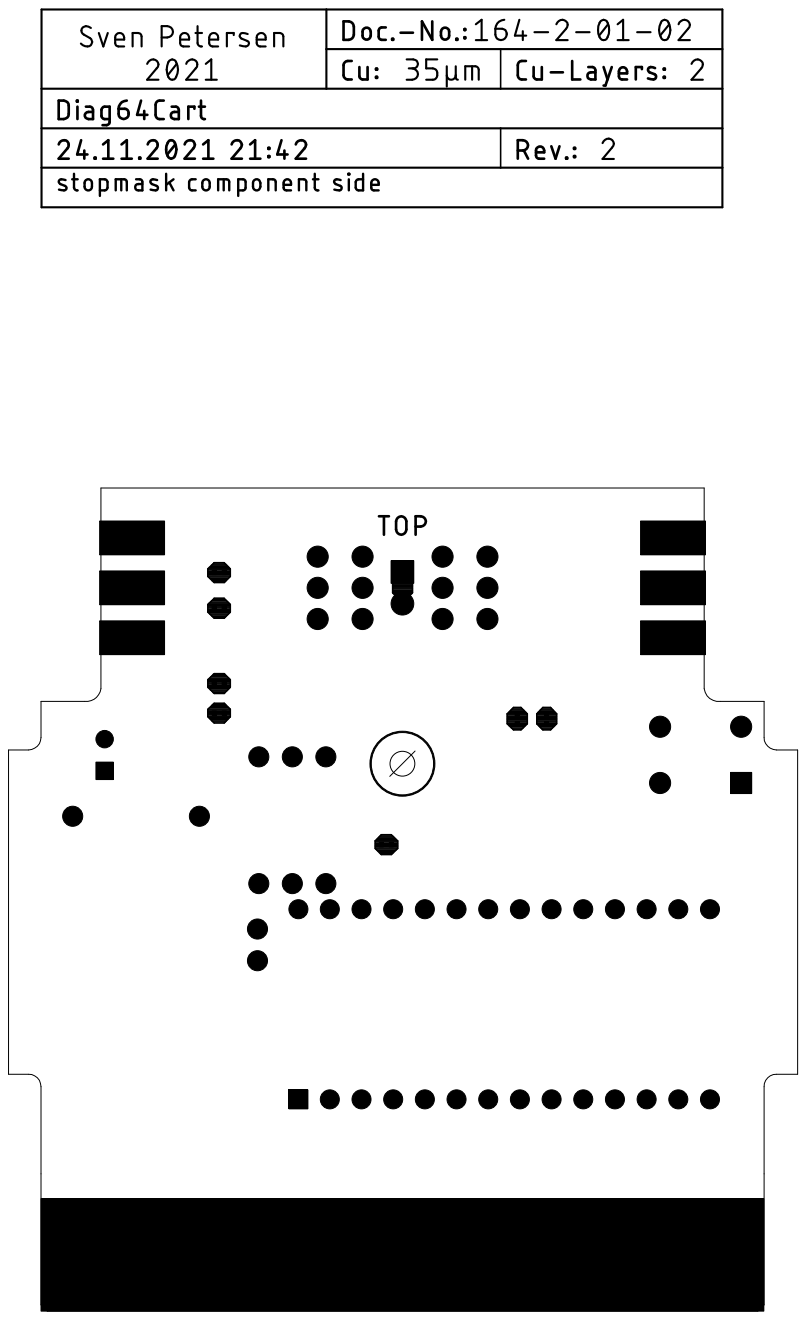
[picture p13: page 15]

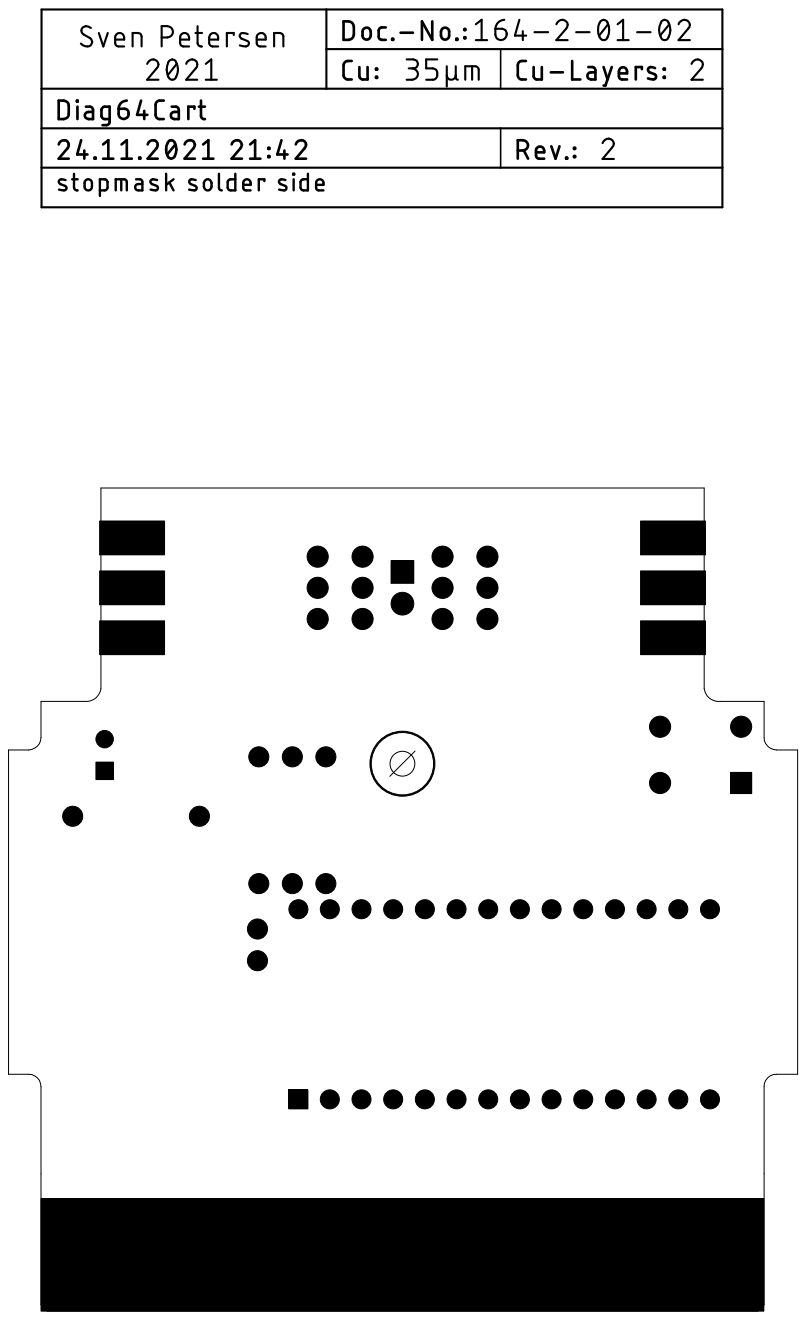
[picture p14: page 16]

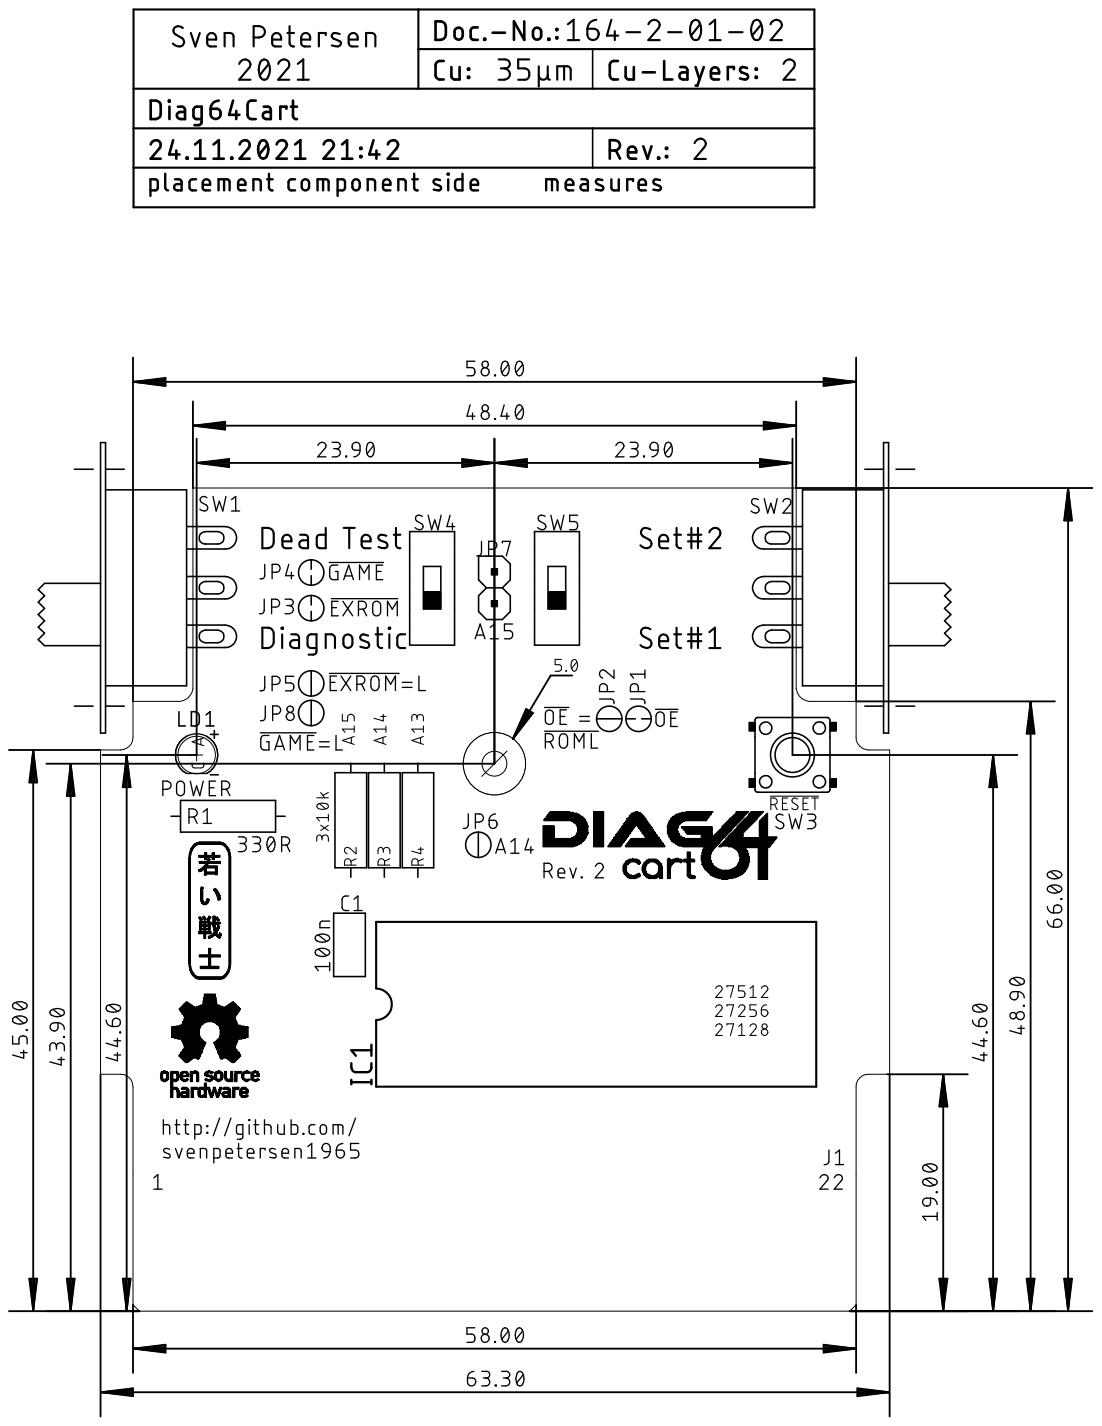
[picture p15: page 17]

Pos. Qty Value Footprint Ref.-No. Comment

1 1 164-2-01-02 2 Layer PCB Rev. 2 2 layer, Cu 35µ, HASL, 66.0 x 63.3, 1.6mm FR4

2 1 100n C-2,5 C1 ceramic capacitor, pitch 2.54

3 3 10k R-10 R2, R3, R4 metal film resistor, 10% or better

4 1 27C512-DIP28 DIL28-6 IC1 EPROM. Also possible: 27C256, 27C128 and 27C64

5 1 JTP-1130 JTP-1130 SW3 Standard 6x6mm tact switch, e.g. Namae JTP-1130 or any

other

6 2 MSS22D18 DPDT_9MM SW4, SW5 alternative switch. AliExpress.

7 2 T217 T217_SIDE SW1, SW2 Reichelt.de: T217 or AliExpress SS22F25-G7 (see Doc.-No.

164-6-01-**)

8 1 KM-20 cartridge case Maszczyk. restore-store.de or tme.eu

### 9 Z7 alternative cartridge case Kradex. restore-store.de or tme.eu

## Commodore C64: Diag64cart Rev. 2

## Bill of Material Rev. 2.0

Diag64cart_BOM_v2_0.xlsx

Drafted by Sven Petersen Page 1 of 1

24.11.2021 22:05
Doc.No.: 164-5-01-02.0

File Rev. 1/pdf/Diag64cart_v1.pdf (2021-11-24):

# Project Documentation

## Commodore C64: Diag64cart

## Project number: 164

## Revision: 1

## Date: 17.02.2021


Diag64_ModD.docx | | 24.11.2021 22:16
Drafted by Sven Petersen | Page 1 of 8 | Doc.-No.: 164-6-01-01

### Commodore C64: Diag64cart Rev. 1

### Module Description

Table of Contents

## Introduction

The Diag64cart is a C64/C128 cartridge PCB, that is especially made for the need of diagnostic software, like Dead Test Rev. 781220 and Diagnostic Rev. 586220. The Diag64cart is derived from the Versa64cart (https://github.com/bwack/Versa64Cart), it lacks of the ability to be a 16k cartridge, though.

The geometry of this cart was especially made for the cheap Maszczyk (https://www.maszczyk.pl/en.html) KM-20 and the Kradex (https://www.kradex.de/) Z7 cartridge cases. Those are available from https://restore-store.de/ or https://www.tme.eu.

Dead Test and Diagnostic reside in two different address spaces of the C64. Also, they are differently configured via GAME or EXROM and use different chip select signals ( ROMH or ROML ).

Drafted by Sven Petersen | Page 2 of 8 | Doc.-No.: 164-6-01-01

## Select Switches

While Dead Test replaces the Kernal, Diagnostic is an 8k auto-start cartridge at address $8000. Diag64cart has a fix assignment of EPROM offset addresses (via A13) and the cartridge type, which is done by the left DTDP switch SW1.

The right switch (SW2) only switches the EPROM offset address A14. This results in four possible software banks in the EPROM. The use of 27C256 or 27C512 is recommended.

The switches are a cheap, simple and comfortable way to reconfigure the cartridge for the different diagnostic tools. The configuration of the cartridge can be modified with solder bridges.

SW1 | SW2 | GAME | EXROM
Chip Select | A13 | A14 | Type | EPROM
down | down | HIGH | LOW | ROML | LOW | LOW | Diagnostic | $0000
up | down | LOW | HIGH | ROMH | HIGH | LOW | Dead Test | $2000
down | up | HIGH | LOW | ROML | LOW | HIGH | Diagnostic | $4000
up | up | LOW | HIGH | ROMH | HIGH | HIGH | Dead Test | $6000

Table 1: Default Configuration: assignment of switches and software type

The connection between SW1, GAME , EXROM , chip select and A13 implies an order of the type of software/cartridge in the EPROM memory.

Do not confuse the EPROM offset address with the memory address of the cartridge in the C64/C128. A selected cartridge will appear in the computer’s address, that is specified by the chip

select (that is $8000 for ROML and $C000 for ROMH ). The EPROM offset address is the address in the programming buffer/EPROM, where the binaries reside.

## Configuration with solder bridges

The default configuration is described in the previous chapter. This can be modified with solder bridges.

E.G. the C128 works differently than the C64. If the C128 finds either GAME or EXROM LOW, it will boot into the C64 mode. For a C128 cartridge, both signals have to be high.

Solder bridge Default When closed | Note
JP1 | closed | Chip select ( OE ) switched by SW1 | If JP2 is closed, open JP1
JP2 | open | Chip select always ROML | e.g. for only diagnostic software or C128 mode only
JP3 | closed | EXROM switched by SW1, A13 = EXROM | Open for permanent settings for EXROM
JP4 | closed | GAME switched by SW1 | Open for permanent settings for GAME
JP5 | open | EXROM always LOW | e.g. for C64 diagnostic only
JP6 | open | A14 always LOW | In case only two software required and A14 not installed

Drafted by Sven Petersen | Page 3 of 8 | Doc.-No.: 164-6-01-01
Solder bridge Default When closed | Note
JP7 | open | A15 always LOW | Close for EPROM type 27C512
JP8 | open | GAME always LOW | e.g. for C64 dead test only

Table 2: Configuration of the solder bridges

## Example configurations

### EPROM Type 27C512

If a 27C512 is used, it might be desired to program the EPROM starting at offset address $0000. For this purpose, A15 has to be LOW. This requires JP7 to be closed.

### EPROM Type 27C256

This is the default EPROM type. No modifications are required. JP7 is open be default, that means A15 is HIGH (that is the VPP input on a 27C256).

### EPROM Type 27C128

This 16k EPROM can hold two 8k software. In this case, SW2 (which switches A14 between LOW and HIGH =open, due to the pull-up resistor). In a 27C128, this pin is /PGM, which should be HIGH. The switch SW2 can just be omitted, no further modification required, since the pull-up resistor R3 does the job.

### EPROM Type 27C64

This is actually an abuse, since a 27C64 can only hold 8k of software. So, no switch is required at all. A13 (Pin 26) is a “not connected” pin of the EPROM. The pull-up R4 can stay. It does not harm the function of the EPROM, but it is not required. In case the cartridge software resides in $8000, close JP2 and JP5. An 8k cartridge at $C000 can be achieved by bridging the solder pads of SW1 to mimic it in up position. The solder pads of the alternative switch SW4 might come in handy in this case.

### C64 and C128 Diagnostic Cartridge

The C128 requires both, GAME and EXROM to be HIGH (=open) and the chip select ( OE ) to

be ROML . For this purpose, open JP4 and JP1 and close JP2. While the 8k memory at $0000 and $4000 are reserved for C64 software and the 8k memory banks at $2000 and $6000 are reserved for C128 cartridge software.

### C128 Cartridge Only

Again, both , GAME and EXROM , have to be HIGH (=open) and the chip select ( OE ) has to

be ROML . For this purpose, open JP1, JP3, JP4 and close JP2.

### C64 Diagnostic Cartridge Only

In case it is desired to have all software reside at $8000, GAME needs to be open, EXROM needs

to be low and the chip select has to be ROML . For this purpose, open JP1, JP3 and JP4 and close JP2 and JP5.

Drafted by Sven Petersen | Page 4 of 8 | Doc.-No.: 164-6-01-01

## Switches

The switches SW1 and SW2 are built in sideways. They are DPDT slide switches with a pin pitch of 4mm. The hole distance is 19mm (which is not important for this project, but just a part of the switches specification). The height of the switch body is 6.9mm. This is met be the reichelt.de part number T217 or the AliExpress SS22F25-G7, but obviously, there are more 199mm pitch panel mount switches, that meet these specifications.

Alternatively, there are footprints (SW4 and SW5) for the also wide spread AliExpress mini slide switches MSS22D18.

## EPROMs

Four different types/sizes of EPROMs can be used with the Versa64Cart, not all settings make sense with them. Their pin out is shown in Table 3.

The effect of the settings and the recommended configurations are shown in Table 4.

27C64

| 27C128
| 27C256
| 27C512
| SOCKET
Vpp | Vpp | Vpp | A15 | 1 | A15 | VCC | 28 | VCC | VCC | VCC | VCC
A12 | A12 | A12 | A12 | 2 | A12 | A14 | 27 | A14 | A14 | /PGM | /PGM
A7 | A7 | A7 | A7 | 3 | A7 | A13 | 26 | A13 | A13 | A13 | n.c.
A6 | A6 | A6 | A6 | 4 | A6 | A8 | 25 | A8 | A8 | A8 | A8
A5 | A5 | A5 | A5 | 5 | A5 | A9 | 24 | A9 | A9 | A9 | A9
A4 | A4 | A4 | A4 | 6 | A4 | A11 | 23 | A11 | A11 | A11 | A11
A3 | A3 | A3 | A3 | 7 | A3 | /OE | 22 | /G/Vpp | /G | /G | /G
A2 | A2 | A2 | A2 | 8 | A2 | A10 | 21 | A10 | A10 | A10 | A10
A1 | A1 | A1 | A1 | 9 | A1 | GND | 20 | /E | /E | /E | /E
A0 | A0 | A0 | A0 | 10 | A0 | D7 | 19 | D7 | D7 | D7 | D7
D0 | D0 | D0 | D0 | 11 | D0 | D6 | 18 | D6 | D6 | D6 | D6
D1 | D1 | D1 | D1 | 12 | D1 | D5 | 17 | D5 | D5 | D5 | D5
D2 | D2 | D2 | D2 | 13 | D2 | D4 | 16 | D4 | D4 | D4 | D4
GND | GND | GND | GND | 14 | GND | D3 | 15 | D3 | D3 | D3 | D3

Table 3: EPROM pin compatibility

Drafted by Sven Petersen | Page 5 of 8 | Doc.-No.: 164-6-01-01
EPROM | Size | A15 | A14 | A13 | 16k
27C512 | 64kx8 | yes | yes | yes | yes
27C256 | 32kx8 | HIGH | yes | yes | yes
27C128 | 16kx8 | HIGH | HIGH | yes | yes
27C64 | 8kx8 | HIGH | HIGH | HIGH | no
Table 4: Settings per EPROM type

In case Vpp is located at a dedicated pin (pin 1), A15 has no effect anymore. A HIGH level is recommended (switch is off) . The /PGM Pin should be set HIGH. The n.c. (not connected) pin should be HIGH (with pull-up) or open. For an 8k EPROM, the 16k setting makes no sense.

## Using parallel EEPROMs

There are parallel EPROMs, which fit into the EPROM sockets. They do not require erasing with a UV eraser, like EPROMs, but the price is higher.

Since they can be written, which is controlled by the WE signal, but the Super Expander II cartridge is lacking of this functionality, this signal has to be HIGH (inactive). The 28C256 has the A14 signal connected to Pin 1, which is A15 of the EEPROM socket. This is no problem, but it has to be kept in mind, that the jumper for A15 has effect on the bank select A14 of the EPROM.

28C64

| 28C256
| SOCKET
n.c. | A14 | 1 | A15 | VCC | 28 | VCC | VCC
A12 | A12 | 2 | A12 | A14 | 27 | /WE | /WE
A7 | A7 | 3 | A7 | A13 | 26 | A13 | n.c
A6 | A6 | 4 | A6 | A8 | 25 | A8 | A8
A5 | A5 | 5 | A5 | A9 | 24 | A9 | A9
A4 | A4 | 6 | A4 | A11 | 23 | A11 | A11
A3 | A3 | 7 | A3 | /OE | 22 | /G/Vpp | /OE
A2 | A2 | 8 | A2 | A10 | 21 | A10 | A10
A1 | A1 | 9 | A1 | GND | 20 | /E | /CE
A0 | A0 | 10 | A0 | D7 | 19 | D7 | D7
D0 | D0 | 11 | D0 | D6 | 18 | D6 | D6
D1 | D1 | 12 | D1 | D5 | 17 | D5 | D5
D2 | D2 | 13 | D2 | D4 | 16 | D4 | D4
GND | GND | 14 | GND | D3 | 15 | D3 | D3

Table 5: EEPROM pin compatibility

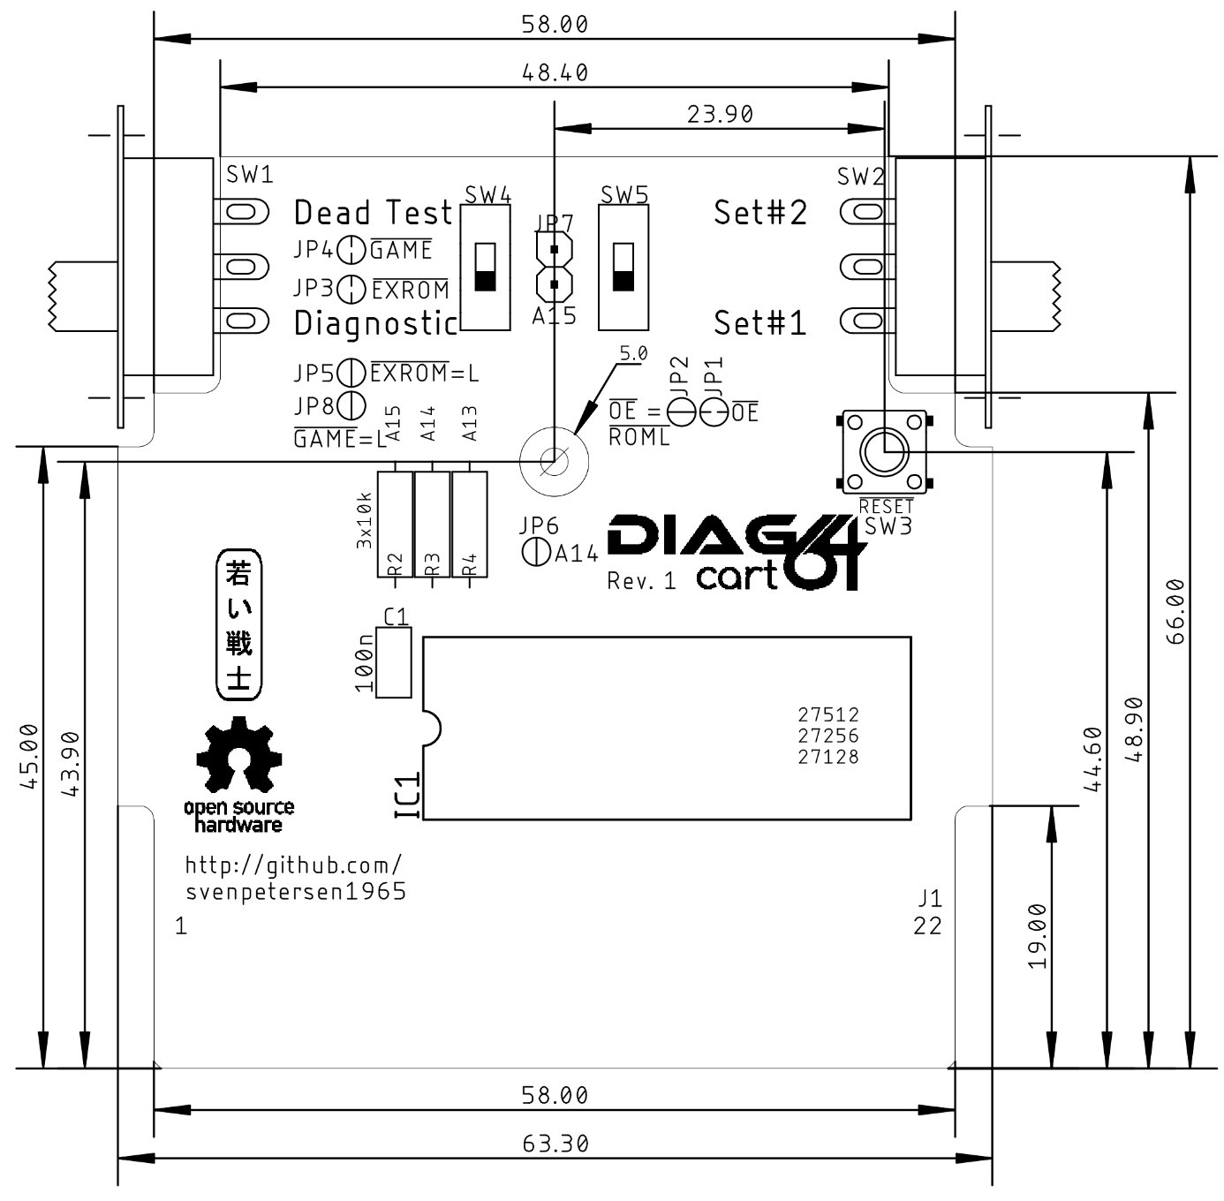
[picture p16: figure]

Drafted by Sven Petersen | Page 6 of 8 | Doc.-No.: 164-6-01-01
EEPROM | Size | A15 | A14 | A13
28C256 | 32kx8 | =A14 | OPEN | yes
28C64 | 8kx8 | OPEN | OPEN | OPEN
Table 6: Settings per EEPROM type

## Dimensions

The dimensions are made to fit the said cartridge cases.

Figure 1: Dimensions

The Maszczyk KM-20 and the Kradex Z7 cartridge cases both fit the Diag64cart. The dimensions are slightly different, though.

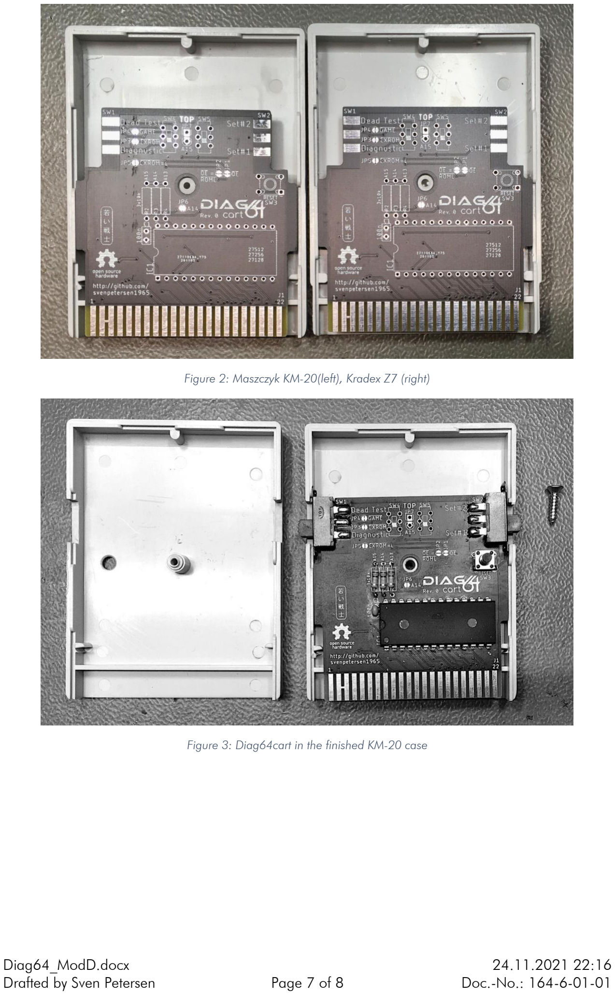
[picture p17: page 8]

Drafted by Sven Petersen | Page 7 of 8 | Doc.-No.: 164-6-01-01

Figure 2: Maszczyk KM-20(left), Kradex Z7 (right)

Figure 3: Diag64cart in the finished KM-20 case

Drafted by Sven Petersen | Page 8 of 8 | Doc.-No.: 164-6-01-01

## Suggested Software

This cartridge is made for C64 (and C128) Diagnostic software. So, the selection of suggested software is for this kind of purpose.

1. (Commodore) Diagnostic Rev. 586220 (C64) (Version +0.5)
2. (Commodore) Dead Test Rev. 781220 (C64)

### 3. STID Dead Test (v1.2.0)

4. (Commodore) Diagnostic Rev. 785260 (C128)
5. (Commodore) Diagnostic Rev. 588121 (C128)
6. 1541 Diagnostic (World of Jani)
7. Diag 4.1.1.

Diagnostic Rev. 586220 and Diag. 4.1.1 work with the same diagnostic harness (https://github.com/svenpetersen1965/C64-Diagnostic-Rev.-586220-Harness). While Diagnostic Rev. 586220 is still the diagnostic tool of my choice, Diag 4.1.1 is a bit different and might be useful as a second instance.

Dead Test Rev. 781220 is THE dead test program, that can reveal RAM problems without requiring a working display. The first-choice software to debug a black screen.

STID Dead Test is a modification of the Commodore Dead Test Rev. 781220 it has some nice new features (e.g. tests the SID filters). It can be obtained here: https://github.com/stid/kick-c64-dead-test. (https://github.com/stid/kick-c64-dead-test) The binary files can be found in the releases of this project. No compiling and building required.

The 1541 Diagnostics is a very nice toolkit for testing and debugging a Commodore 1541 (or Oceanic OC-118) disk drive. It can be obtained here: http://blog.worldofjani.com/?p=2180

I have downloaded all other binaries from World of Jani: http://blog.worldofjani.com/?p=164

## Revision History

### Rev. 0

- Fully functional prototype

### Rev. 1

- JP8 new

### - Lower corner of the “shoulders” was moved down by 6mm (19mm instead of 25mm) to

reduce the movement of the PCB.

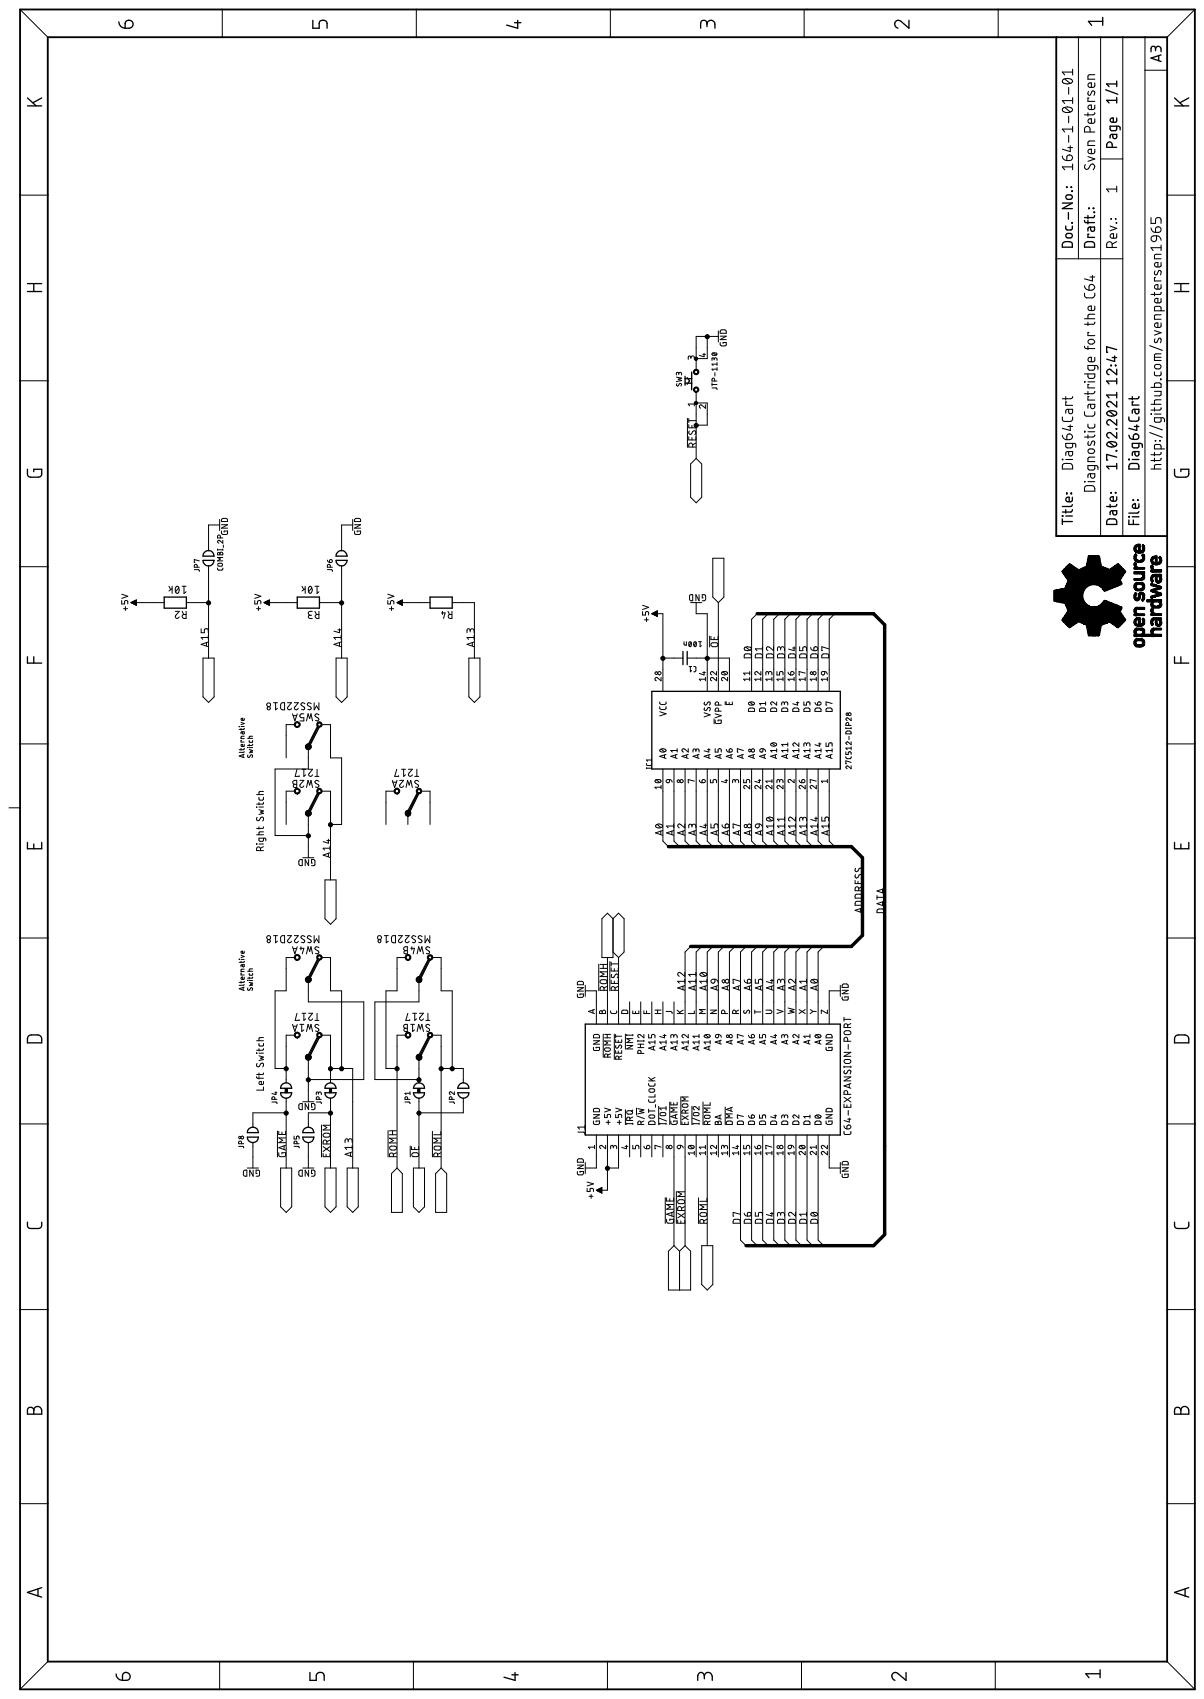
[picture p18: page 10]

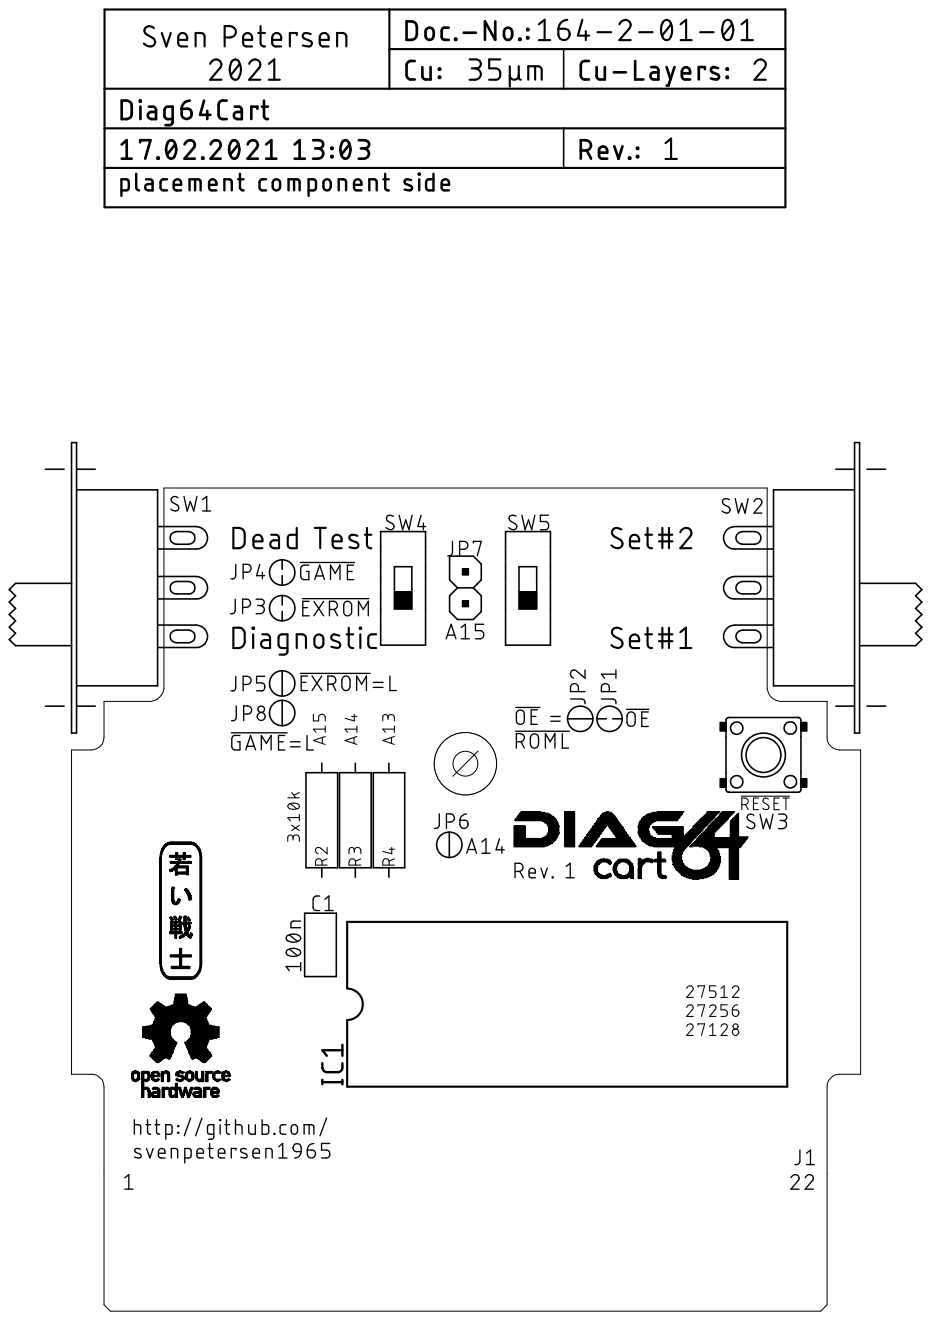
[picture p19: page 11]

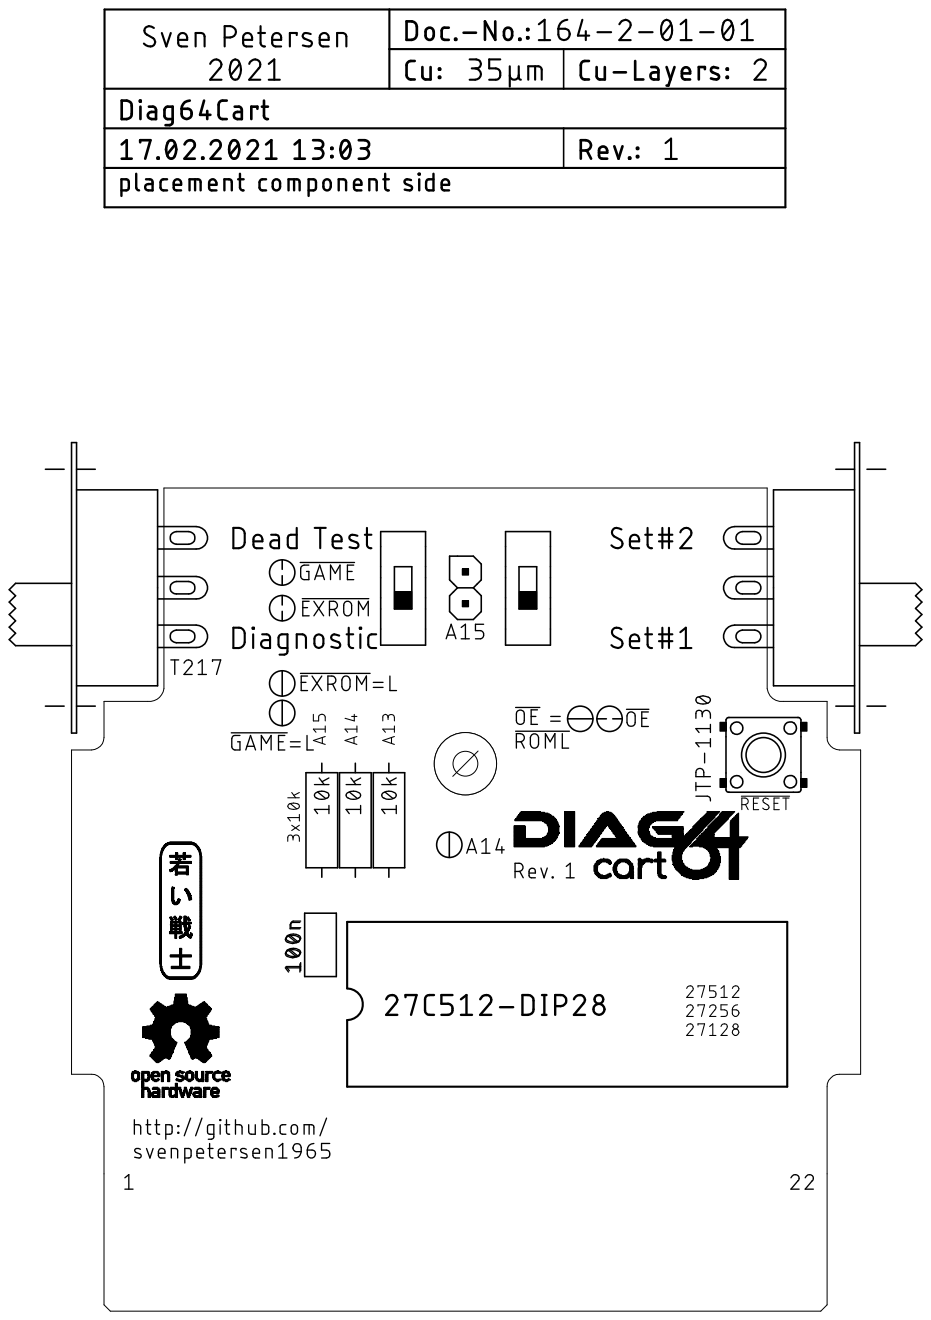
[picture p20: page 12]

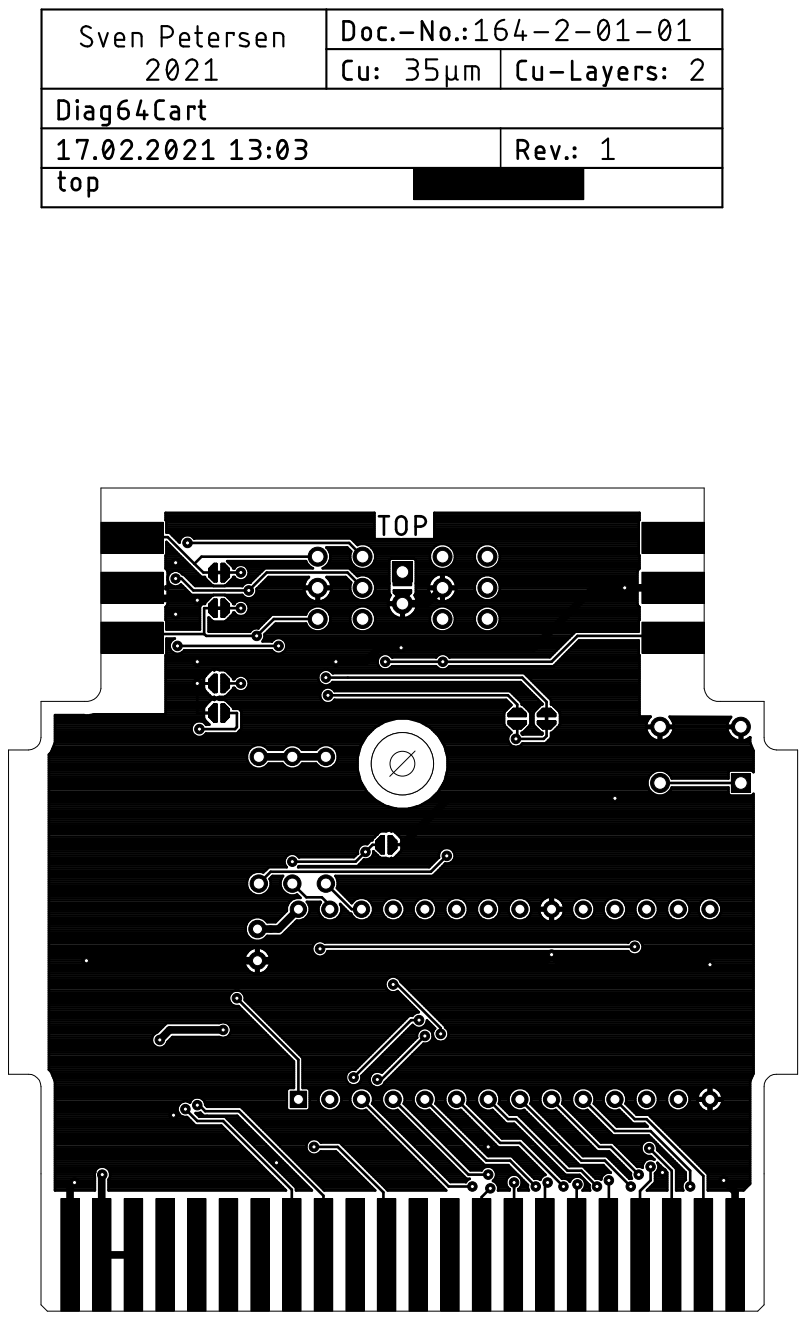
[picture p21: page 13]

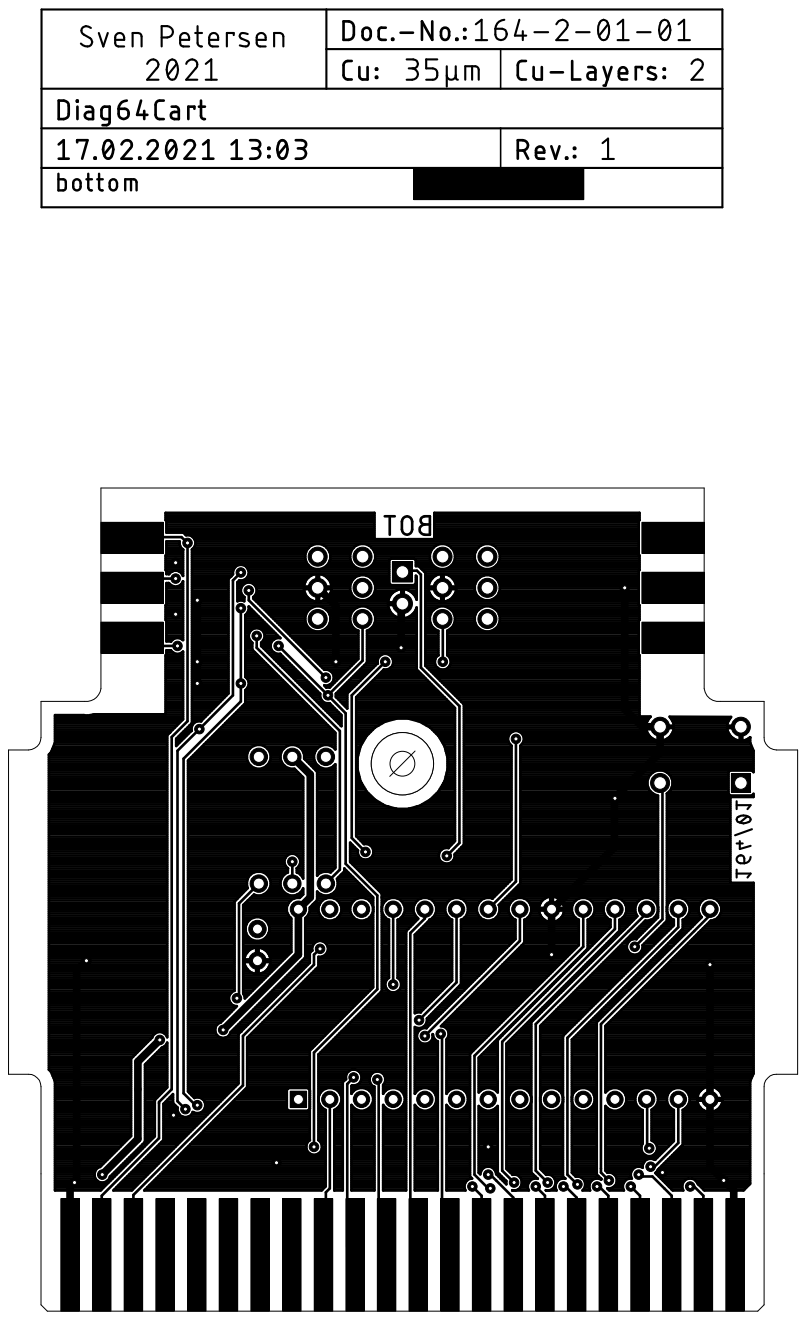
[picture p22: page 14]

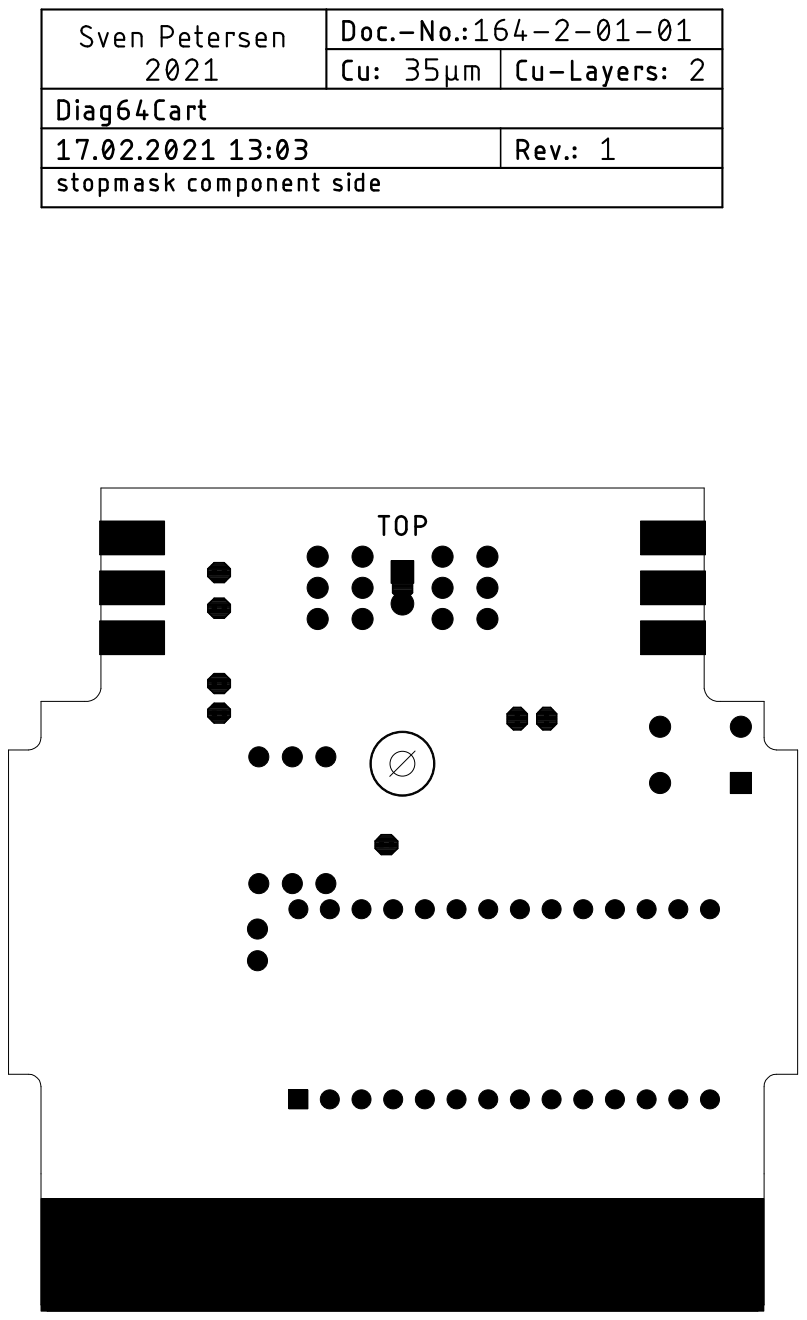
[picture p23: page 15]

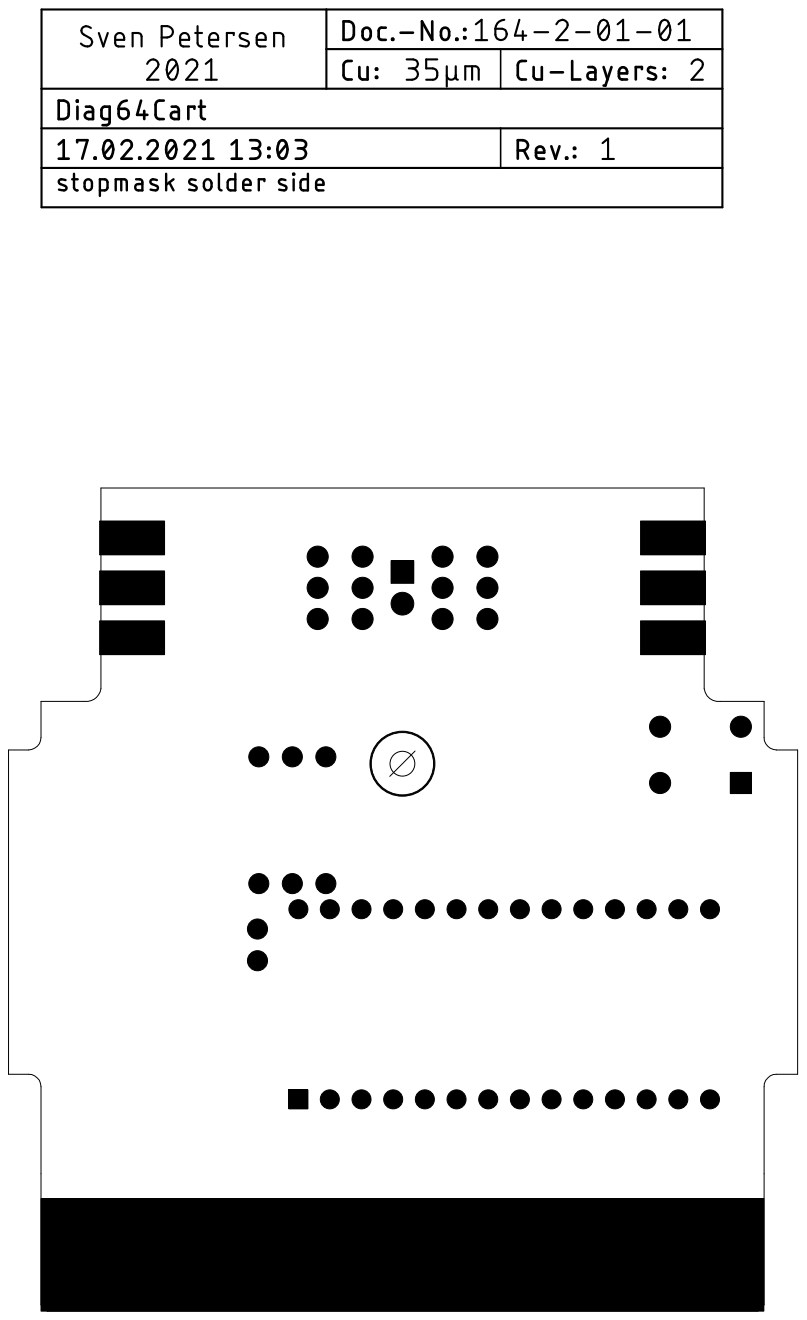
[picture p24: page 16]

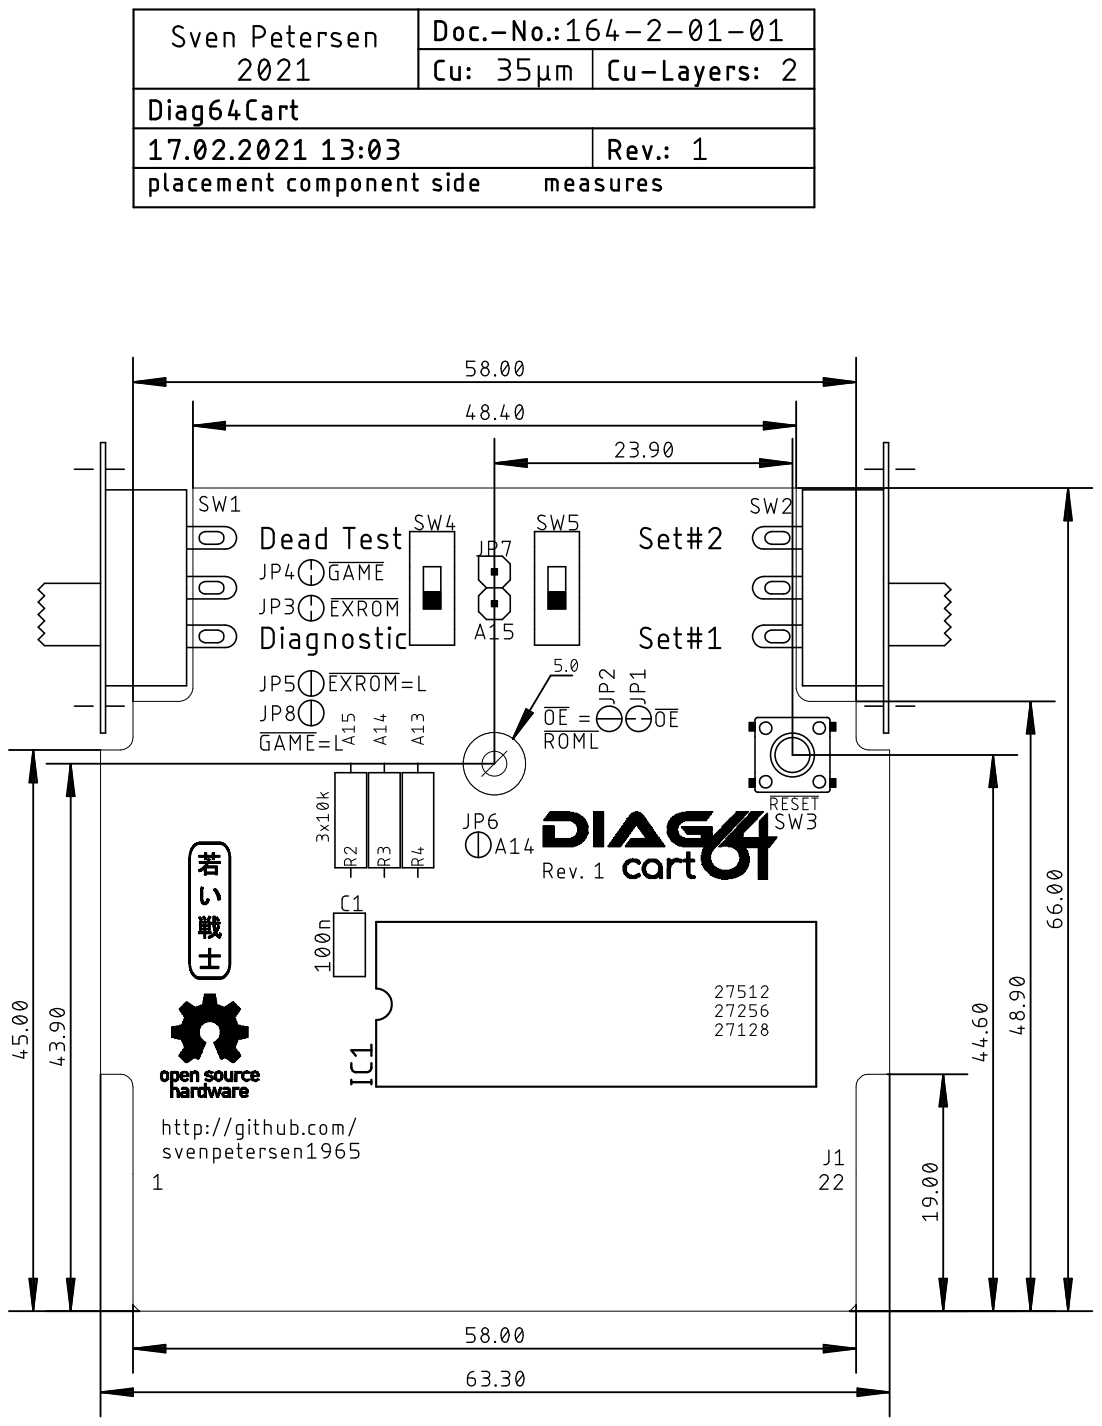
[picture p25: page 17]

Pos. Qty Value Footprint Ref.-No. Comment

1 1 164-2-01-01 2 Layer PCB Rev. 1 2 layer, Cu 35µ, HASL, 66.0 x 63.3, 1.6mm FR4

2 1 100n C-2,5 C1 ceramic capacitor, pitch 2.54

3 3 10k R-10 R2, R3, R4 metal film resistor, 10% or better

4 1 27C512-DIP28 DIL28-6 IC1 EPROM. Also possible: 27C256, 27C128 and 27C64

5 1 JTP-1130 JTP-1130 SW3 Standard 6x6mm tact switch, e.g. Namae JTP-1130 or any

other

6 2 MSS22D18 DPDT_9MM SW4, SW5 alternative switch. AliExpress.

7 2 T217 T217_SIDE SW1, SW2 Reichelt.de: T217 or AliExpress SS22F25-G7 (see Doc.-No.

164-6-01-**)

8 1 KM-20 cartridge case Maszczyk. restore-store.de or tme.eu

### 9 Z7 alternative cartridge case Kradex. restore-store.de or tme.eu

## Commodore C64: Diag64cart Rev. 1

## Bill of Material Rev. 1.0

Diag64cart_BOM_v1_0.xlsx

Drafted by Sven Petersen Page 1 of 1

24.11.2021 22:17
Doc.No.: 164-5-01-01.0

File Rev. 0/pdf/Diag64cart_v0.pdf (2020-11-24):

# Project Documentation

## Commodore C64: Diag64cart

## Project number: 164

## Revision: 0

## Date: 25.10.2020


Diag64_ModD.docx | | 24.11.2020 19:32
Drafted by Sven Petersen | Page 1 of 8 | Doc.-No.: 164-6-01-00

### Commodore C64: Diag64cart Rev. 0

### Module Description

Table of Contents

## Introduction

The Diag64cart is a C64/C128 cartridge PCB, that is especially made for the need of diagnostic software, like Dead Test Rev. 781220 and Diagnostic Rev. 586220. The Diag64cart is derived from the Versa64cart (https://github.com/bwack/Versa64Cart), it lacks of the ability to be a 16k cartridge, though.

The geometry of this cart was especially made for the cheap Maszczyk (https://www.maszczyk.pl/en.html) KM-20 and the Kradex (https://www.kradex.de/) Z7 cartridge cases. Those are available from https://restore-store.de/ or https://www.tme.eu.

Dead Test and Diagnostic reside in two different address spaces of the C64. Also, they are differently configured via GAME or EXROM and use different chip select signals ( ROMH or ROML ).

## Select Switches

While Dead Test replaces the Kernal, Diagnostic is an 8k auto-start cartridge at address $8000. Diag64cart has a fix assignment of EPROM offset addresses (via A13) and the cartridge type, which is done by the left DTDP switch SW1.

Drafted by Sven Petersen | Page 2 of 8 | Doc.-No.: 164-6-01-00

The right switch (SW2) only switches the EPROM offset address A14. This results in four possible software banks in the EPROM. The use of 27C256 or 27C512 is recommended.

The switches are a cheap, simple and comfortable way to reconfigure the cartridge for the different diagnostic tools. The configuration of the cartridge can be modified with solder bridges.

SW1 | SW2 | GAME | EXROM
Chip Select | A13 | A14 | Type | EPROM
down | down | HIGH | LOW | ROML | LOW | LOW | Diagnostic | $0000
up | down | LOW | HIGH | ROMH | HIGH | LOW | Dead Test | $2000
down | up | HIGH | LOW | ROML | LOW | HIGH | Diagnostic | $4000
up | up | LOW | HIGH | ROMH | HIGH | HIGH | Dead Test | $6000

Table 1: Default Configuration: assignment of switches and software type

The connection between SW1, GAME , EXROM , chip select and A13 implies an order of the type of software/cartridge in the EPROM memory.

Do not confuse the EPROM offset address with the memory address of the cartridge in the C64/C128. A selected cartridge will appear in the computer’s address, that is specified by the chip

select (that is $8000 for ROML and $C000 for ROMH ). The EPROM offset address is the address in the programming buffer/EPROM, where the binaries reside.

## Configuration with solder bridges

The default configuration is described in the previous chapter. This can be modified with solder bridges.

E.G. the C128 works differently than the C64. If the C128 finds either GAME or EXROM LOW, it will boot into the C64 mode. For a C128 cartridge, both signals have to be high.

Solder bridge Default When closed | Note
JP1 | closed | Chip select ( OE ) switched by SW1 | If JP2 is closed, open JP1
JP2 | open | Chip select always ROML | e.g. for only diagnostic software or C128 mode only
JP3 | closed | EXROM switched by SW1, A13 = EXROM | Open for permanent settings for EXROM
JP4 | closed | GAME switched by SW1 | Open for permanent settings for GAME
JP5 | open | EXROM always LOW | e.g. for C64 diagnostic only
JP6 | open | A14 always LOW | In case only two software required and A14 not installed
JP7 | open | A15 always LOW | Close for EPROM type 27C512

Table 2: Configuration of the solder bridges

Drafted by Sven Petersen | Page 3 of 8 | Doc.-No.: 164-6-01-00

## Example configurations

### EPROM Type 27C512

If a 27C512 is used, it might be desired to program the EPROM starting at offset address $0000. For this purpose, A15 has to be LOW. This requires JP7 to be closed.

### EPROM Type 27C256

This is the default EPROM type. No modifications are required. JP7 is open be default, that means A15 is HIGH (that is the VPP input on a 27C256).

### EPROM Type 27C128

This 16k EPROM can hold two 8k software. In this case, SW2 (which switches A14 between LOW and HIGH =open, due to the pull-up resistor). In a 27C128, this pin is /PGM, which should be HIGH. The switch SW2 can just be omitted, no further modification required, since the pull-up resistor R3 does the job.

### EPROM Type 27C64

This is actually an abuse, since a 27C64 can only hold 8k of software. So, no switch is required at all. A13 (Pin 26) is a “not connected” pin of the EPROM. The pull-up R4 can stay. It does not harm the function of the EPROM, but it is not required. In case the cartridge software resides in $8000, close JP2 and JP5. An 8k cartridge at $C000 can be achieved by bridging the solder pads of SW1 to mimic it in up position. The solder pads of the alternative switch SW4 might come in handy in this case.

### C64 and C128 Diagnostic Cartridge

The C128 requires both, GAME and EXROM to be HIGH (=open) and the chip select ( OE ) to

be ROML . For this purpose, open JP4 and JP1 and close JP2. While the 8k memory at $0000 and $4000 are reserved for C64 software and the 8k memory banks at $2000 and $6000 are reserved for C128 cartridge software.

### C128 Cartridge Only

Again, both , GAME and EXROM , have to be HIGH (=open) and the chip select ( OE ) has to

be ROML . For this purpose, open JP1, JP3, JP4 and close JP2.

### C64 Diagnostic Cartridge Only

In case it is desired to have all software reside at $8000, GAME needs to be open, EXROM needs

to be low and the chip select has to be ROML . For this purpose, open JP1, JP3 and JP4 and close JP2 and JP5.

## Switches

The switches SW1 and SW2 are built in sideways. They are DPDT slide switches with a pin pitch of 4mm. The hole distance is 19mm (which is not important for this project, but just a part of the switches specification). The height of the switch body is 6.9mm. This is met be the reichelt.de part number T217 or the AliExpress SS22F25-G7, but obviously, there are more 199mm pitch panel mount switches, that meet these specifications.

Alternatively, there are footprints (SW4 and SW5) for the also wide spread AliExpress mini slide switches MSS22D18.

Drafted by Sven Petersen | Page 4 of 8 | Doc.-No.: 164-6-01-00

## EPROMs

Four different types/sizes of EPROMs can be used with the Versa64Cart, not all settings make sense with them. Their pin out is shown in Table 3.

The effect of the settings and the recommended configurations are shown in Table 4.

27C64

| 27C128
| 27C256
| 27C512
| SOCKET
Vpp | Vpp | Vpp | A15 | 1 | A15 | VCC | 28 | VCC | VCC | VCC | VCC
A12 | A12 | A12 | A12 | 2 | A12 | A14 | 27 | A14 | A14 | /PGM | /PGM
A7 | A7 | A7 | A7 | 3 | A7 | A13 | 26 | A13 | A13 | A13 | n.c.
A6 | A6 | A6 | A6 | 4 | A6 | A8 | 25 | A8 | A8 | A8 | A8
A5 | A5 | A5 | A5 | 5 | A5 | A9 | 24 | A9 | A9 | A9 | A9
A4 | A4 | A4 | A4 | 6 | A4 | A11 | 23 | A11 | A11 | A11 | A11
A3 | A3 | A3 | A3 | 7 | A3 | /OE | 22 | /G/Vpp | /G | /G | /G
A2 | A2 | A2 | A2 | 8 | A2 | A10 | 21 | A10 | A10 | A10 | A10
A1 | A1 | A1 | A1 | 9 | A1 | GND | 20 | /E | /E | /E | /E
A0 | A0 | A0 | A0 | 10 | A0 | D7 | 19 | D7 | D7 | D7 | D7
D0 | D0 | D0 | D0 | 11 | D0 | D6 | 18 | D6 | D6 | D6 | D6
D1 | D1 | D1 | D1 | 12 | D1 | D5 | 17 | D5 | D5 | D5 | D5
D2 | D2 | D2 | D2 | 13 | D2 | D4 | 16 | D4 | D4 | D4 | D4
GND | GND | GND | GND | 14 | GND | D3 | 15 | D3 | D3 | D3 | D3

Table 3: EPROM pin compatibility

EPROM | Size | A15 | A14 | A13 | 16k
27C512 | 64kx8 | yes | yes | yes | yes
27C256 | 32kx8 | HIGH | yes | yes | yes
27C128 | 16kx8 | HIGH | HIGH | yes | yes
27C64 | 8kx8 | HIGH | HIGH | HIGH | no
Table 4: Settings per EPROM type

In case Vpp is located at a dedicated pin (pin 1), A15 has no effect anymore. A HIGH level is recommended (switch is off) . The /PGM Pin should be set HIGH. The n.c. (not connected) pin should be HIGH (with pull-up) or open. For an 8k EPROM, the 16k setting makes no sense.

Drafted by Sven Petersen | Page 5 of 8 | Doc.-No.: 164-6-01-00

## Using parallel EEPROMs

There are parallel EPROMs, which fit into the EPROM sockets. They do not require erasing with a UV eraser, like EPROMs, but the price is higher.

Since they can be written, which is controlled by the WE signal, but the Super Expander II cartridge is lacking of this functionality, this signal has to be HIGH (inactive). The 28C256 has the A14 signal connected to Pin 1, which is A15 of the EEPROM socket. This is no problem, but it has to be kept in mind, that the jumper for A15 has effect on the bank select A14 of the EPROM.

28C64

| 28C256
| SOCKET
n.c. | A14 | 1 | A15 | VCC | 28 | VCC | VCC
A12 | A12 | 2 | A12 | A14 | 27 | /WE | /WE
A7 | A7 | 3 | A7 | A13 | 26 | A13 | n.c
A6 | A6 | 4 | A6 | A8 | 25 | A8 | A8
A5 | A5 | 5 | A5 | A9 | 24 | A9 | A9
A4 | A4 | 6 | A4 | A11 | 23 | A11 | A11
A3 | A3 | 7 | A3 | /OE | 22 | /G/Vpp | /OE
A2 | A2 | 8 | A2 | A10 | 21 | A10 | A10
A1 | A1 | 9 | A1 | GND | 20 | /E | /CE
A0 | A0 | 10 | A0 | D7 | 19 | D7 | D7
D0 | D0 | 11 | D0 | D6 | 18 | D6 | D6
D1 | D1 | 12 | D1 | D5 | 17 | D5 | D5
D2 | D2 | 13 | D2 | D4 | 16 | D4 | D4
GND | GND | 14 | GND | D3 | 15 | D3 | D3

Table 5: EEPROM pin compatibility

EEPROM | Size | A15 | A14 | A13
28C256 | 32kx8 | =A14 | OPEN | yes
28C64 | 8kx8 | OPEN | OPEN | OPEN
Table 6: Settings per EEPROM type

## Dimensions

The dimensions are made to fit the said cartridge cases.


Drafted by Sven Petersen | Page 6 of 8 | Doc.-No.: 164-6-01-00

Figure 1: Dimensions

The Maszczyk KM-20 and the Kradex Z7 cartridge cases both fit the Diag64cart. The dimensions are slightly different, though.


Drafted by Sven Petersen | Page 7 of 8 | Doc.-No.: 164-6-01-00

Figure 2: Maszczyk KM-20(left), Kradex Z7 (right)

Figure 3: Diag64cart in the finished KM-20 case

Drafted by Sven Petersen | Page 8 of 8 | Doc.-No.: 164-6-01-00

## Suggested Software

This cartridge is made for C64 (and C128) Diagnostic software. So, the selection of suggested software is for this kind of purpose.

1. (Commodore) Diagnostic Rev. 586220 (C64) (Version +0.5)
2. (Commodore) Dead Test Rev. 781220 (C64)

### 3. STID Dead Test (v1.2.0)

4. (Commodore) Diagnostic Rev. 785260 (C128)
5. (Commodore) Diagnostic Rev. 588121 (C128)
6. 1541 Diagnostic (World of Jani)
7. Diag 4.1.1.

Diagnostic Rev. 586220 and Diag. 4.1.1 work with the same diagnostic harness (https://github.com/svenpetersen1965/C64-Diagnostic-Rev.-586220-Harness). While Diagnostic Rev. 586220 is still the diagnostic tool of my choice, Diag 4.1.1 is a bit different and might be useful as a second instance.

Dead Test Rev. 781220 is THE dead test program, that can reveal RAM problems without requiring a working display. The first-choice software to debug a black screen.

STID Dead Test is a modification of the Commodore Dead Test Rev. 781220 it has some nice new features (e.g. tests the SID filters). It can be obtained here: https://github.com/stid/kick-c64-dead-test. (https://github.com/stid/kick-c64-dead-test) The binary files can be found in the releases of this project. No compiling and building required.

The 1541 Diagnostics is a very nice toolkit for testing and debugging a Commodore 1541 (or Oceanic OC-118) disk drive. It can be obtained here: http://blog.worldofjani.com/?p=2180

I have downloaded all other binaries from World of Jani: http://blog.worldofjani.com/?p=164

## Revision History

### Rev. 0

- Fully functional prototype










Pos. Qty Value Footprint Ref.-No. Comment

1 1 164-2-01-00 2 Layer PCB Rev. 0 2 layer, Cu 35µ, HASL, 66.0 x 63.3, 1.6mm FR4

2 1 100n C-2,5 C1 ceramic capacitor, pitch 2.54

3 3 10k R-10 R2, R3, R4 metal film resistor, 10% or better

4 1 27C512-DIP28 DIL28-6 IC1 EPROM. Also possible: 27C256, 27C128 and 27C64

5 1 JTP-1130 JTP-1130 SW3 Standard 6x6mm tact switch, e.g. Namae JTP-1130 or any

other

6 2 MSS22D18 DPDT_9MM SW4, SW5 alternative switch. AliExpress.

7 2 T217 T217_SIDE SW1, SW2 Reichelt.de: T217 or AliExpress SS22F25-G7 (see Doc.-No.

164-6-01-**)

8 1 KM-20 cartridge case Maszczyk. restore-store.de or tme.eu

### 9 Z7 alternative cartridge case Kradex. restore-store.de or tme.eu

## Commodore C64: Diag64cart Rev. 0

## Bill of Material Rev. 0.0

Diag64cart_BOM_v0_0.xlsx

Drafted by Sven Petersen Page 1 of 1

24.11.2020 22:33
Doc.No.: 164-5-01-00.0

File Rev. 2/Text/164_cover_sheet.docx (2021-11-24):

Project Documentation

Commodore C64: Diag64cart

Project number: 164

Revision: 2

Date: 24.11.2021


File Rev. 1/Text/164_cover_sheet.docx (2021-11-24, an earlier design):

Project Documentation

Commodore C64: Diag64cart

Project number: 164

Revision: 1

Date: 17.02.2021


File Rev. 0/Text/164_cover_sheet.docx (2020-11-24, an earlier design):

Project Documentation

Commodore C64: Diag64cart

Project number: 164

Revision: 0

Date: 25.10.2020


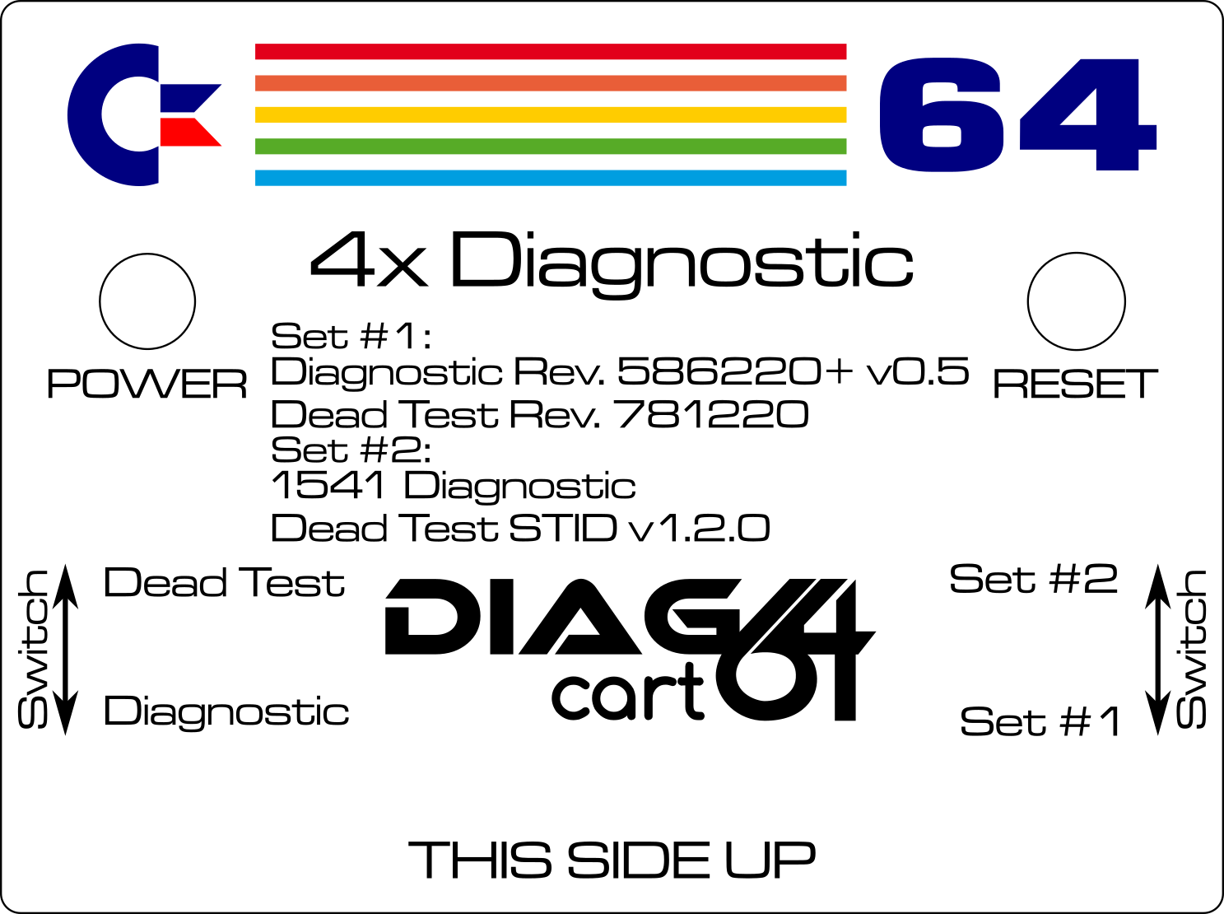
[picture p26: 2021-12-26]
case_label/Diagnostic_4X_Label_Rev.2.png

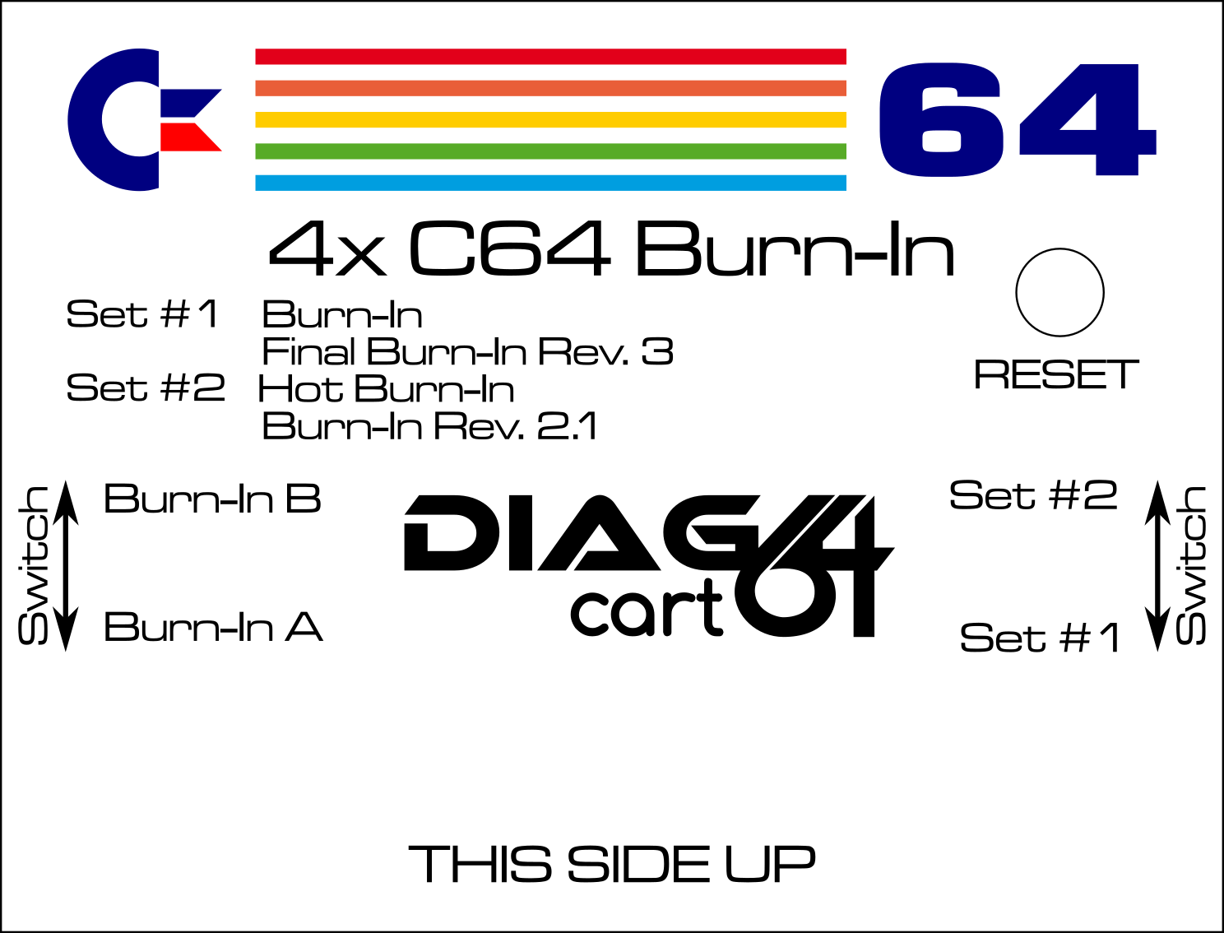
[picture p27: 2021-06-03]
case_label/C64_4x_Burn-In.png

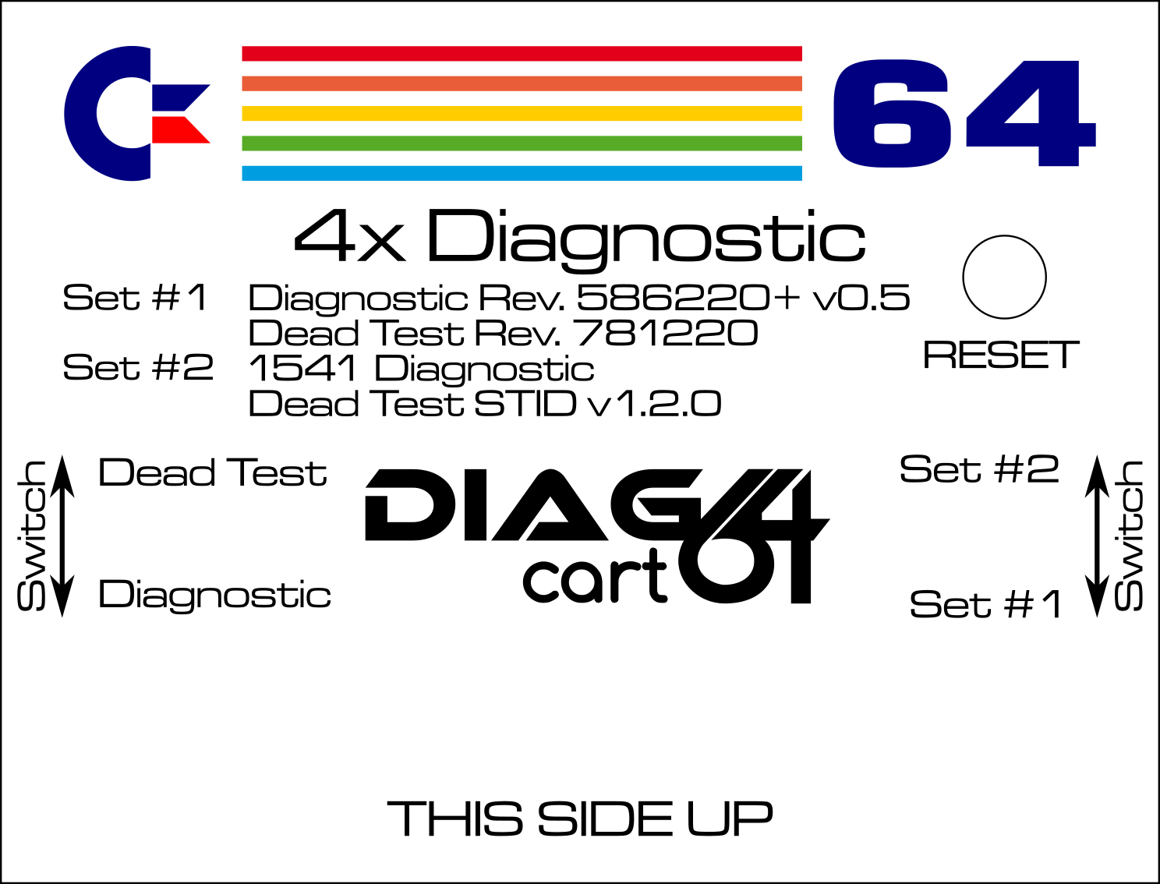
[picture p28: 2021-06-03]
case_label/Diagnostic_4X_label.png

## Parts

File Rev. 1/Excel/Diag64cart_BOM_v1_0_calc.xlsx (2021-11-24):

Commodore C64: Diag64cart Rev. 1
Calculation Rev. 1.0
Pos. | Qty | Value | €/ea | € | Comment
1 | 1 | 164-2-01-00 | 1.00 € | 1.00 € | 2 layer, Cu 35µ, HASL, 66.0 x 63.3, 1.6mm FR4
2 | 1 | 100n | 0.20 € | 0.20 € | ceramic capacitor, pitch 2.54
3 | 3 | 10k | 0.08 € | 0.24 € | metal film resistor, 10% or better
4 | 1 | 27C512-DIP28 | 5.50 € | 5.50 € | EPROM. Also possible: 27C256, 27C128 and 27C64
5 | 1 | JTP-1130 | 0.15 € | 0.15 € | Standard 6x6mm tact switch, e.g. Namae JTP-1130 or any other
6 | 0 | MSS22D18 | 0.00 € | 0.00 € | alternative switch. AliExpress.
7 | 2 | T217 | 0.35 € | 0.70 € | Reichelt.de: T217 or AliExpress SS22F25-G7 (see Doc.-No. 164-6-01-**)
8 | 1 | KM-20 | 2,0 | 2.00 € | Maszczyk. restore-store.de or tme.eu
9 | 0 | Z7 | 0 | 0.00 € | Kradex. restore-store.de or tme.eu
 |  | Total |  | 9.79 €

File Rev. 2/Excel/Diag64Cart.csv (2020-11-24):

Qty | Value | Device | Package | Parts | Description
3 |  | CLOSED | CP_CL | JP1, JP3, JP4 | Closed Cutpad
3 |  | OPEN | CP_OP | JP2, JP5, JP6 | open Cutpad
1 | 100n | CAP01 | C-2,5 | C1
3 | 10k | RES04 | R-10 | R2, R3, R4
1 | 27C512-DIP28 | M27C512-DIP28 | DIL28-6 | IC1
1 | C64-EXPANSION-PORT | C64-EXPANSIONPNARROW | EXPANSIO_SQ | J1
1 | COMBI_2P | COMBI_2P | COMBI-2P | JP7
1 | JTP-1130 | JTP-1130 | JTP-1130 | SW3
2 | MSS22D18 | DPDT_9MM | DPDT_9MM | SW4, SW5
1 | OPEN_SOURCE_HW | OPEN_SOURCE_HW | OPENHW | U$43
2 | T217 | T217 | T217_SIDE | SW1, SW2

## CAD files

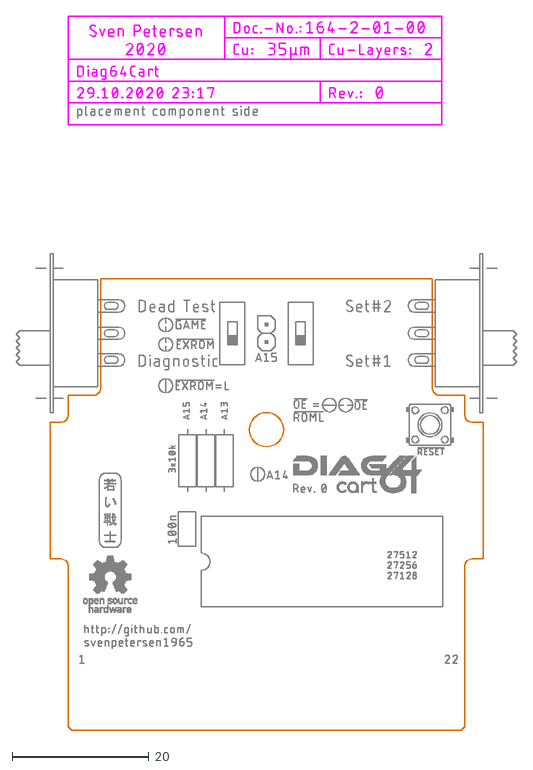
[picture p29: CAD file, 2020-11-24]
Rev. 0/dxf/Diag64Cart.dxf
73.2 x 104.4

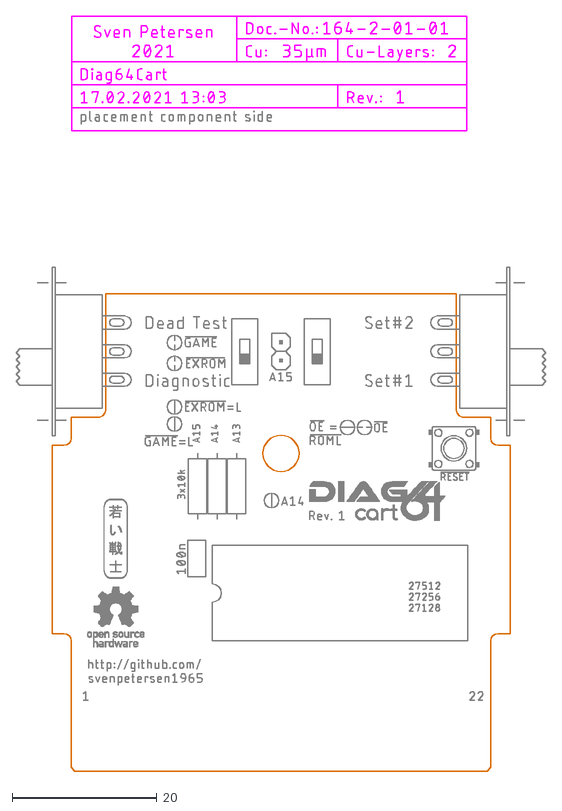
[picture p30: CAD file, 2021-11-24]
Rev. 1/dxf/Diag64Cart.dxf
73.2 x 104.4

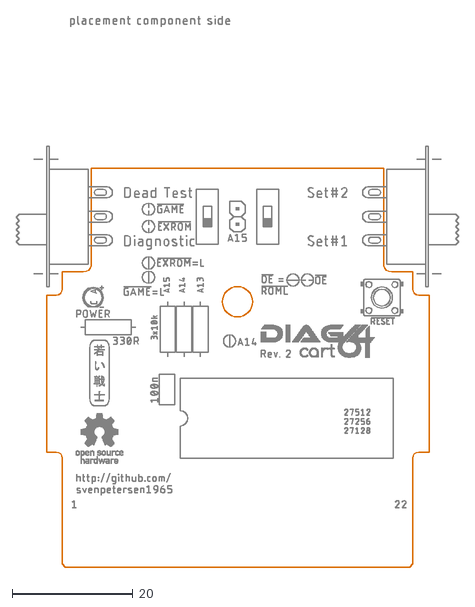
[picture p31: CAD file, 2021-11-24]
Rev. 2/dxf/Diag64Cart.dxf
73.2 x 91.2

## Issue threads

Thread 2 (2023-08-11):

Kradex Z7 Case Issue

oXL0C0Xo, 2023-08-11:
I wasn't able to get this to fit into the Kradex Z7 case

https://www.tme.com/us/en-us/details/z7-abs/multipurpose-enclosures/kradex/z7-abs/

The shaft in the center is larger diameter than the hole in the PCB. Looking at your photo, it looks like they may have made a change to the case.
The shaft in the Top half of the case is 6.15mm in diameter
The shaft in the Bottom half of the case is 7.15mm in diameter

Thanks,
Bryon

svenpetersen1965, 2023-08-11:
Hi Byron,
would you show me a picture, please?
Regards,
Sven

oXL0C0Xo, 2023-08-11:
Here's the bottom

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

oXL0C0Xo, 2023-08-11:
Here's the top, but I don't think it's an issue because it should be bigger than the hole to hold the cartridge down correct?
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

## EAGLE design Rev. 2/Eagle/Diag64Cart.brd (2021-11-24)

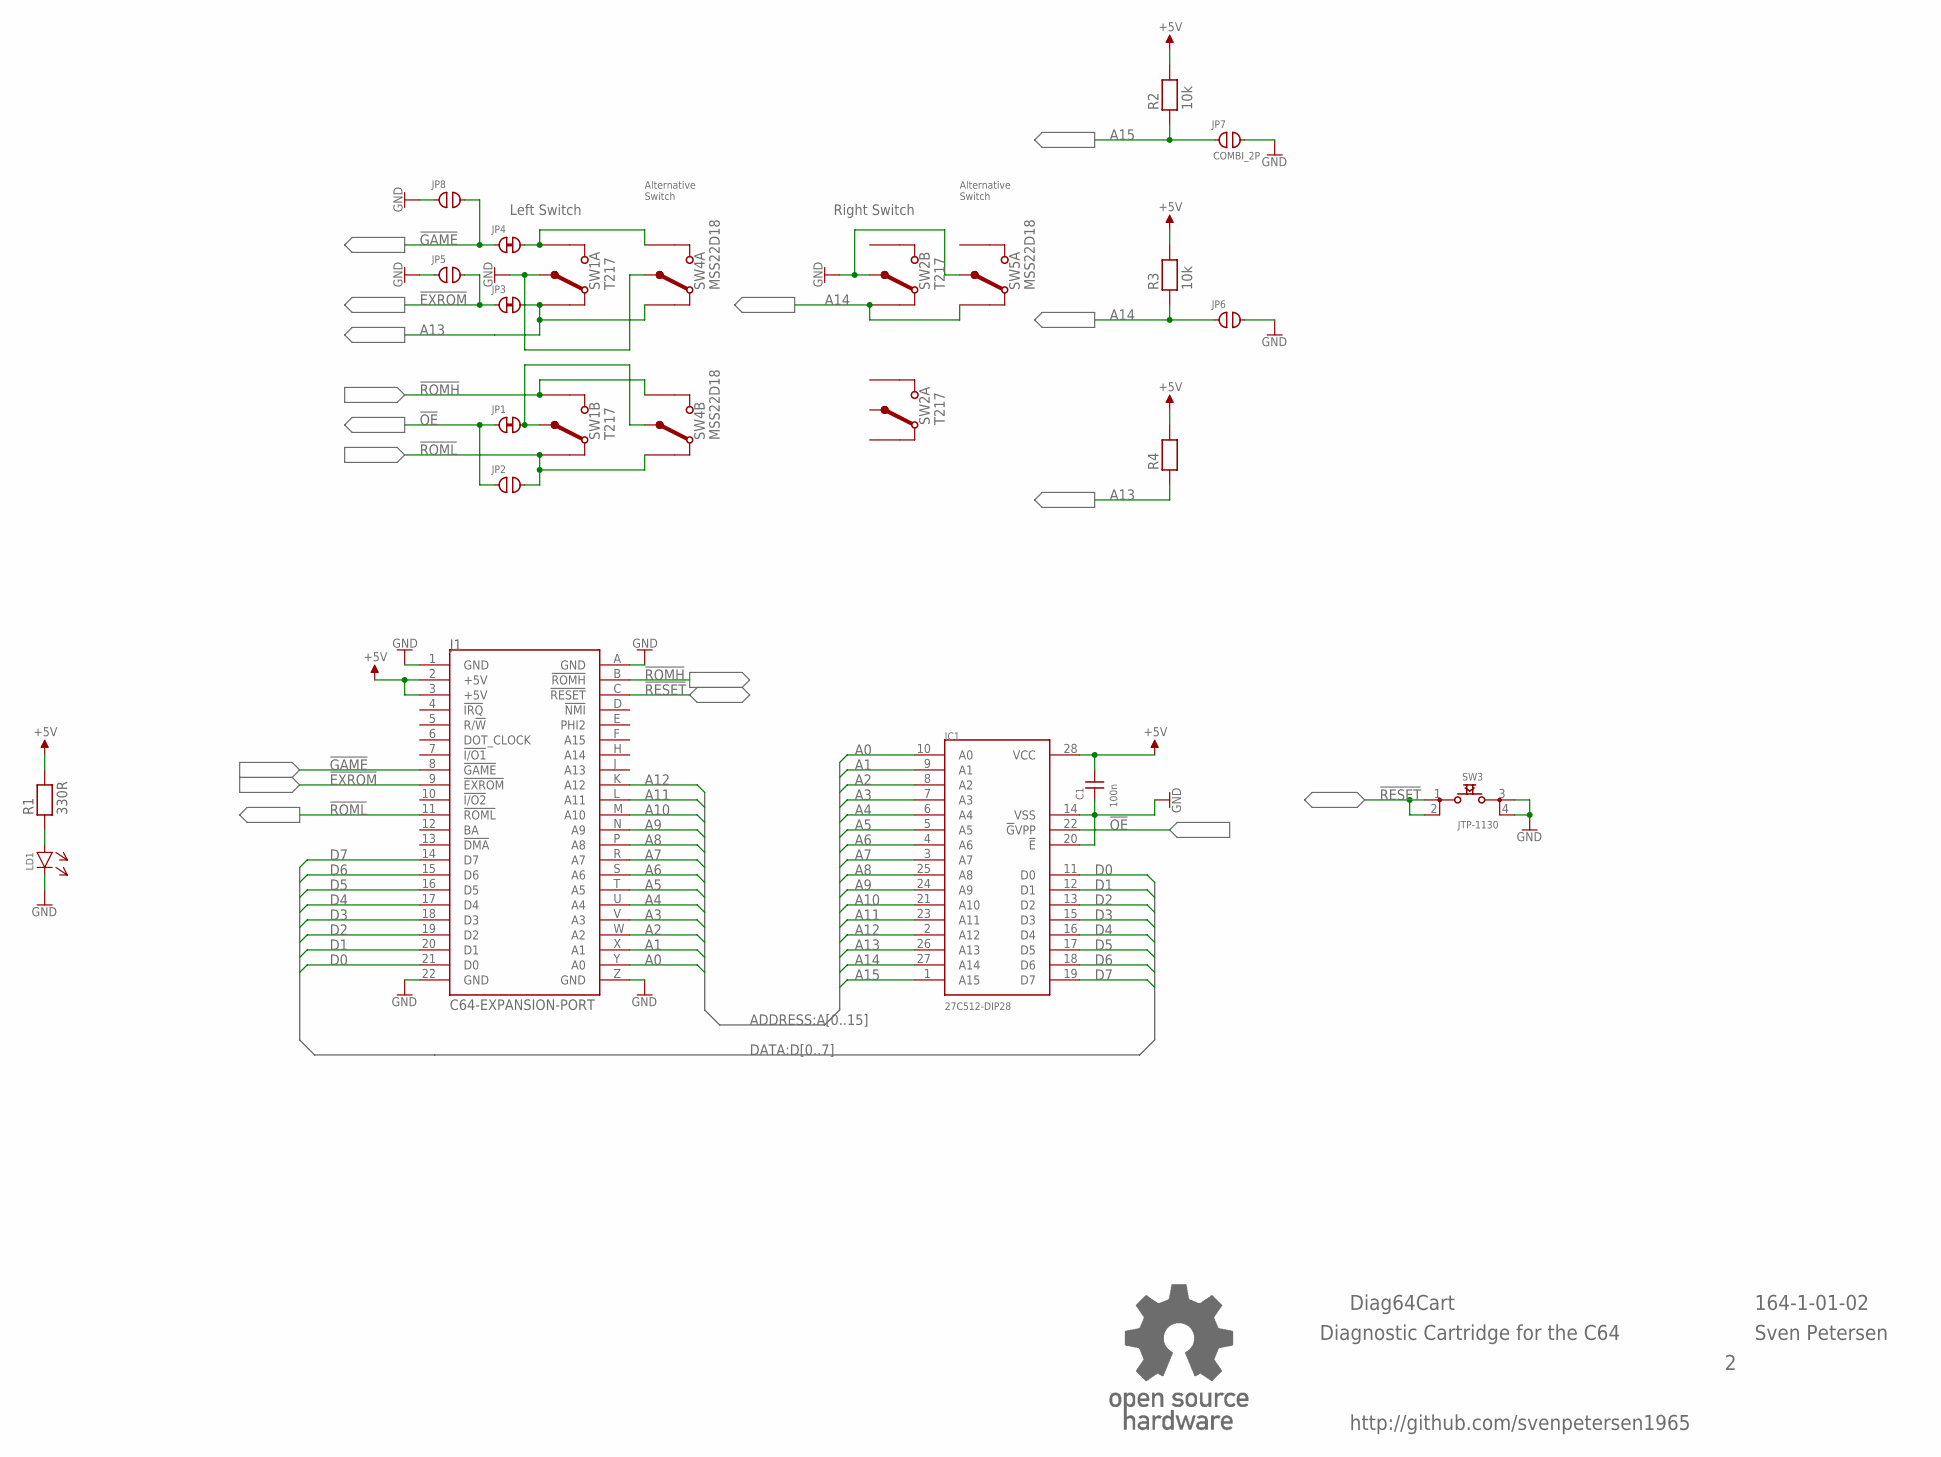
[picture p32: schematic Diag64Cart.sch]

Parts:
C1: 100n; C-2,5
IC1: 27C512-DIP28; DIL28-6
J1: C64-EXPANSION-PORT; EXPANSIO_SQ
JP1, JP3, JP4: CLOSED; CP_CL
JP2, JP5, JP6, JP8: OPEN; CP_OP
JP7: COMBI_2P; COMBI-2P
LD1: 3MM
R1: 330R; R-10
R2, R3, R4: 10k; R-10
SW1, SW2: T217; T217_SIDE
SW3: JTP-1130
SW4, SW5: MSS22D18; DPDT_9MM
U$43: OPEN_SOURCE_HW; OPENHW

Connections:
!EXROM: J1.9 (!EXROM), JP3.1, JP5.2
!GAME: J1.8 (!GAME), JP4.1, JP8.2
!OE: IC1.22 (!G!VPP), JP1.1, JP2.1
!RESET: J1.C (!RESET), SW3.1, SW3.2
!ROMH: J1.B (!ROMH), SW1.UP2 (UP), SW4.6 (UP)
!ROML: J1.11 (!ROML), JP2.2, SW1.DWN2 (DWN), SW4.4 (DWN)
+5V: C1.2, IC1.28 (VCC), J1.2 (+5V), J1.3 (+5V), R1.2, R2.2, R3.2, R4.2
A0: IC1.10 (A0), J1.Y (A0)
A1: IC1.9 (A1), J1.X (A1)
A2: IC1.8 (A2), J1.W (A2)
A3: IC1.7 (A3), J1.V (A3)
A4: IC1.6 (A4), J1.U (A4)
A5: IC1.5 (A5), J1.T (A5)
A6: IC1.4 (A6), J1.S (A6)
A7: IC1.3 (A7), J1.R (A7)
A8: IC1.25 (A8), J1.P (A8)
A9: IC1.24 (A9), J1.N (A9)
A10: IC1.21 (A10), J1.M (A10)
A11: IC1.23 (A11), J1.L (A11)
A12: IC1.2 (A12), J1.K (A12)
A13: IC1.26 (A13), JP3.2, R4.1, SW1.DWN1 (DWN), SW4.3 (DWN)
A14: IC1.27 (A14), JP6.1, R3.1, SW2.DWN2 (DWN), SW5.3 (DWN)
A15: IC1.1 (A15), JP7.1, R2.1
D0: IC1.11 (D0), J1.21 (D0)
D1: IC1.12 (D1), J1.20 (D1)
D2: IC1.13 (D2), J1.19 (D2)
D3: IC1.15 (D3), J1.18 (D3)
D4: IC1.16 (D4), J1.17 (D4)
D5: IC1.17 (D5), J1.16 (D5)
D6: IC1.18 (D6), J1.15 (D6)
D7: IC1.19 (D7), J1.14 (D7)
GND: C1.1, IC1.14 (VSS), IC1.20 (!E), J1.1 (GND), J1.22 (GND), J1.A (GND), J1.Z (GND), JP5.1, JP6.2, JP7.2, JP8.1, LD1.C (K), SW1.COM1 (COM), SW2.COM2 (COM), SW3.3, SW3.4, SW4.2 (COM), SW5.2 (COM)
unnamed: JP4.2, SW1.UP1 (UP), SW4.1 (UP)
unnamed: LD1.A, R1.1
unnamed: JP1.2, SW1.COM2 (COM), SW4.5 (COM)

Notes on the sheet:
Diag64Cart
Sven Petersen
164-1-01-02
http://github.com/svenpetersen1965
Left Switch
Right Switch
Diagnostic Cartridge for the C64
Alternative Switch

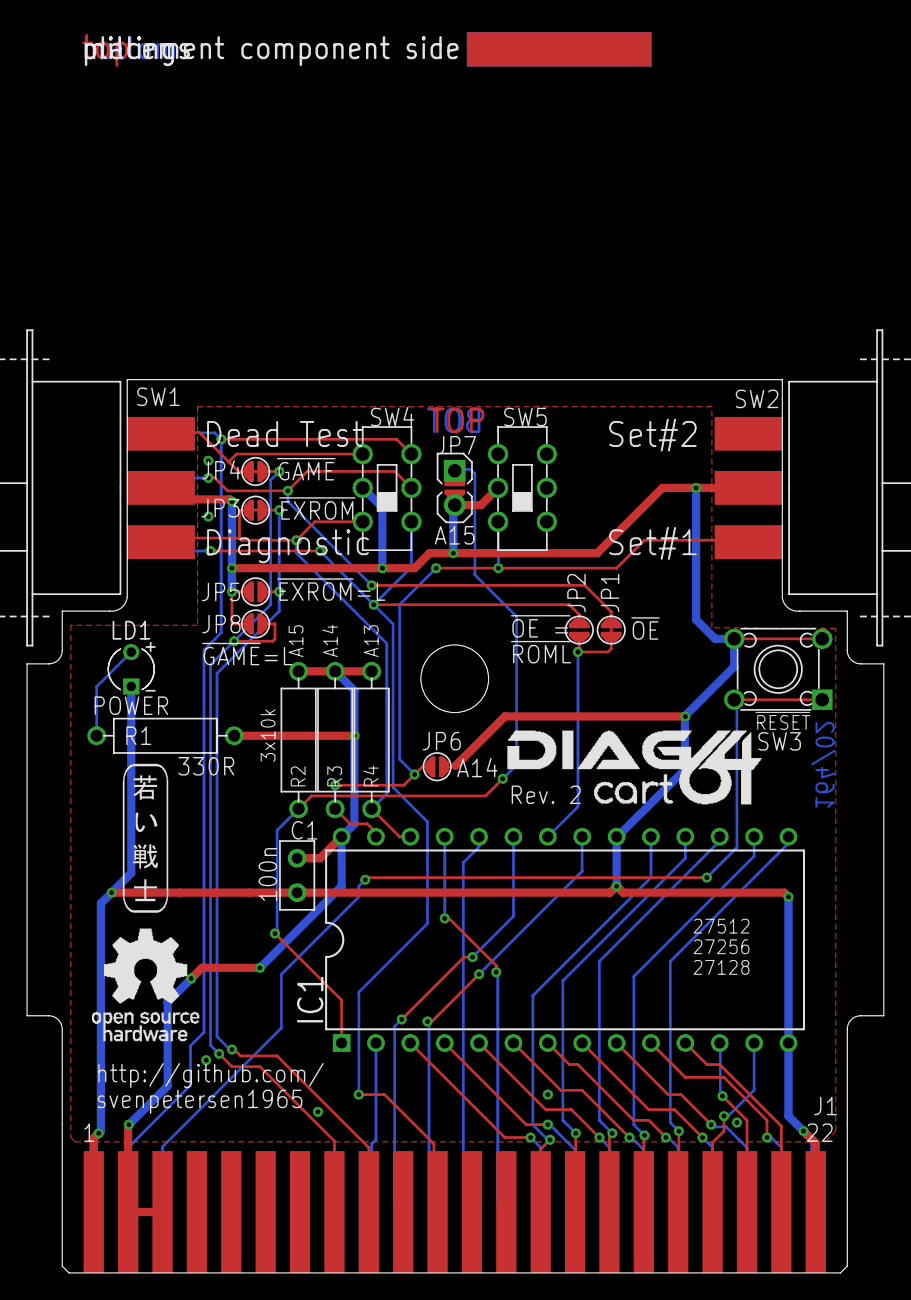
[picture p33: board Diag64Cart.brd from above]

Board: 2 copper layers, 63.3 x 66.0 mm, 26 parts (1 on the bottom side), 35 nets.

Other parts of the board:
U$26: DIAG64CART
U$40: 2LAYER
U$41: PCB-TITLE/
U$42: SVEN_TAG

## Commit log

2020-12-12 Calculation added
    [Diag64cart_BOM_v0_0_calc.xlsx]
2021-11-24 Rev. 1 released
    Minor mechanical changes
    [Diag64Cart.brd, Diag64Cart.csv, Diag64Cart.dxf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]
2021-11-24 Rev. 2 released
    Power LED added
    [Diag64Cart.brd, Diag64Cart.csv, Diag64Cart.dxf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]
2021-12-26 Oskpark compatible gerbers added
2021-12-26 Cas e label Rev. 2 added
    Rev. 2 has a power LED
2021-12-26 Case Label Rev. 2 added
    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
2022-02-26 Gerbers removed
